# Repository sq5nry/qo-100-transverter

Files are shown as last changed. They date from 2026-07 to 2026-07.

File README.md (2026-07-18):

# qo-100-transverter





*[Wersja polska / Polish version](README_PL.md)*

## What it's about
- source-available, hardware and software project of a transverter for the [QO-100](https://amsat-uk.org/satellites/geo/eshail-2/) satellite. The outdoor version takes 1.5 days to assemble starting from bare PCB, bag of parts, and patience.
- complete up and down-converter below 199,99 € : [see the BOM](hw-trv/BOM.md)
- in-fab assembly automation in progress (*v0.3-snapshot*)

## Equipment and skills required
- knack for SMD soldering with stencil and solder paste
- patience for by-hand component placement
- 10x10 cm heat plate and ability to control the temperature profile
- multimeter
- set of fixed attenuators, a variable one and patch cables
- VNA+SA and a signal generator up to 3GHz minimum
- Pluto-like SDR to receive, measure, and generate signals during tests and adjustments
- RF power meter
- 30V 5A lab power supply with over-current protection
- ST-link programmer
- patience for drilling holes in aluminum enclosure
- patience for tapping 3 mm holes
- RF personal protective equipment rated to attenuate 2.4 GHz frequencies

## Features
- QO-100 narrow-band transponder SSB, CW, and Data operation with an HF-VHF transceiver
- ±0.25 ppm reference oscillator stability
- 6W of 2.4GHz output power
- 10m, 6m, 4m, 2m, 70cm bands supported, 5W input power maximum
- 738MHz filtered, receive output for signal supervision
- 25MHz reference oscillator for LNB: injected into the LNB feeder or the shared output
- PTT-over-coax supported
- splash-proof outdoor version

## Block diagram

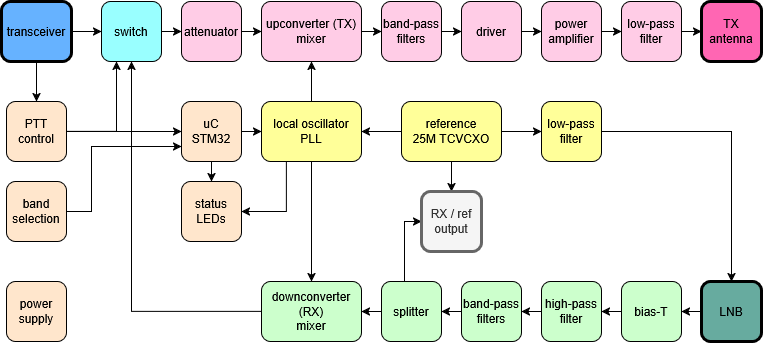
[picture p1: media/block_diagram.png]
block-diagram


## Operation

### Prerequisites

- 28V DC power supply offering 1.1A (31W), or
- 13.8V DC at 3.5A and using the Companion Box for voltage boost
- 60cm dish antenna suggested with 5W ERP according to AMSAT guidelines
- standard universal LNB (13/18V), 500mA fused
- standard PTT ground-to-transmit, or
- PTT-over-coax by transceiver or using the Companion Box to mix PTT and RF
- operation from 13.8V (1.1A) directly is possible with lower output power (2W max). Adequate linearity is not guaranteed.

### Basic procedures

1. Configure IF (Intermediate Frequency) corresponding to your transceiver setup using the three-position slide switch to select one of eight possible IF base frequencies.
2. IF can be updated on-the-fly, the change is indicated by a flashing green LED.
3. Connect DC power and PTT signal.
4. Switch on RX pre-amp in your transceiver.
5. Check the position of the received QO-100 mid beacon, adjust it to fall into the middle of the band using REF ADJ control with a small flat-head screwdriver.
6. Set your transceiver output power to 3–5W and adjust TX ATT control so that your signal is at the mid-beacon level. Lower power with a higher TX ATT setting is advised to minimize heat dissipation inside the transverter.

## Schematics

- [v0.3 schematics (current)](hw-trv/sch_v0.3-sh.pdf)
- [v0.2 schematics](https://github.com/sq5nry/qo-100-transverter/blob/77cc88346982ab3cb6913bec3531f18df363a01a/hw-trv/sch_v0.2.pdf) — release presented at [Ham Radio Friedrichshafen 2026](https://www.hamradio-friedrichshafen.com/trade-show-program/exhibitors/exhibitor?id=107515806) in [PZK](https://www.pzk.org.pl/) (Polish Amateur Radio Union) tent

> **⚠️ Note:** do not mount the OCXO subcircuit (error amplifier and heater components, connected via JP5). This circuitry is non-functional in the current release and will be removed in a future revision. The freed board space can instead be used for additional thermal insulation around the TCXO.

## Assembly

### Preparation

Gather all parts from the [BOM](hw-trv/BOM.md) and arrange them on your workbench before starting.
Verify IC orientation markings and keep ESD-sensitive parts (ICs, MOSFETs) in their packaging
until placement.

### Solder paste application

Apply solder paste through the PCB stencil. Two paste options have been tested:

- **Sn63Pb37** (183°C eutectic, e.g. Mechanic XG-50) — recommended; standard SnPb profile,
  widely available, easy to work with.
- **Sn42Bi58** (~138°C eutectic, e.g. ChipQuik SMD291 or Mechanic UV50) — low-melting-point
  alternative; useful if heat-sensitive components are a concern, but requires careful handling
  as bismuth alloys are more brittle and less compatible with lead-containing component finishes.

Clamp the stencil firmly over the PCB, apply paste with a squeegee in a single smooth stroke,
and lift the stencil straight up to avoid smearing. Inspect paste deposits under magnification
before placing components.

### Component placement

Place all SMD components onto the paste deposits. Work from smallest to largest — passives first,
then ICs. Pay close attention to pin-1 orientation on all ICs and polarised components.
QFN packages require careful centring over their pads; the paste surface tension will self-align
them slightly during reflow.

### Reflow

Place the populated PCB on the heat plate. Follow a standard **SnPb reflow profile**:

| Zone | Temperature | Duration |
|---|---|---|
| Preheat | 100–150°C | ~60 s |
| Soak | 150–180°C | 60–90 s |
| Reflow (above liquidus) | 183–215°C peak | 30–45 s |
| Cooldown | ramp down | natural |

Use hot air to assist reflow around QFN packages and larger thermal-mass parts (PA, DC-DC
converter). Watch for bridging on fine-pitch ICs.

### Inspection and rework

After reflow and cooldown, inspect all joints under magnification:

- Remove solder bridges with braid or a fine soldering iron tip.
- Add solder to any under-filled joints, particularly on exposed thermal pads of QFN/PQFN
  packages — use a soldering iron with flux through the heat-via holes on the bottom side.
- The bottom-side thermal vias do not need to be flush; they will be covered by thermal pads
  connecting to the heat spreader or enclosure floor.

### Through-hole parts

Solder the 5W power resistor by hand after SMD reflow. Mount the TCVCXO with polyester
tape and foam fitting as described in the enclosure assembly notes.

### EMI shields

The PCB has footprints for SMD metal EMI shields over sensitive sections. Mounting the shield over the IF Unit is important for stability. Shielding the switched-mode power supply section and TCXO is recommended but not critical.

### EMI absorber

Most of enclosure types require absorption foams in PA area to help suppress self-oscillations and minimize parasitic coupling between stages. The amplifier may start self-oscillations at a frequency between 2.2-2.5GHz with full power without the absorber. \
See gallery section for a poor's-man approach.

### PCB cleaning

Wash the assembled PCB thoroughly with isopropanol to remove all flux residues before
proceeding. Flux contamination on the board surface can significantly affect 2.4GHz circuit
behaviour — altering tuning, increasing losses, and making RF adjustments unreliable.
Allow the board to dry completely before applying power.

### Power-up and initial checks

Connect power and PTT cables. Supply 28V with the current limit set to 50mA. Measure the
following test points and verify voltages before proceeding:

1. Check 13V and 5V test points first.
2. If those are correct, verify: 3V (analog), 3V (digital), 3.3V (reference oscillator),
   3V (MCU), 9V, and 1.8V.

If any rail is missing or out of range, do not proceed — investigate before applying full power.

### Firmware

Flash the firmware using **STM32CubeProgrammer** via the ST-LINK interface and the SWD ISP
header. A firmware release binary is provided; to build from source use **STM32CubeIDE**.

After programming, the **PLL LOCK** indicator should illuminate. If it does not, check the
25MHz reference oscillator signal.

### PA bias adjustment

Set the quiescent drain current (Idq) for the 2.4GHz PA stages:

- 1st stage: **15mA**
- 2nd stage: **75mA**

Before adjusting, raise the lab supply's overload protection (current limit) to about
**250mA** so it does not trip during bias trimming.

To measure Idq, cut the respective drain supply PCB trace and insert an ammeter in series or just calculate current delta on the lab supply.
Adjust the bias trimmer for each stage until the target Idq is reached, then bridge the cut
with solder.
Adjust the position of C87 in the PA output circuit for highest stage gain.

### PA gain and output matching

Measure the PA gain and adjust the position of C88 to obtain **28–30dB** gain — slide C88 along the output line toward the thicker section. If that alone does not maximise gain, add 0.8pF in parallel with C88. Do not mount
the low-pass filter (LPF) elements yet — bridge the LPF inductor footprint with a strip of
copper foil instead, so the PA output can be measured without the potentially mismatched filter.

Once the gain is set, mount the LPF inductor and adjust it for a maximum insertion loss of
**1dB at 2.4GHz**.

Set the overload (overcurrent) protection threshold to **1.1A**.

Connect an RF power meter to the 2.4GHz TX output socket and adjust the TX path for **6W**
output across your expected input power range (1–5W).

> **⚠️ Warning:** do not increase input power in an attempt to reach 6W until PA gain is at least 28dB. PA chip will overheat and operate non-linearly. I bricked one PA after overloading its input with just 17dBm.

> **⚠️ Warning:** do not drive the PA past **9..12W** output — exceeding this limit pushes the
> stage into non-linear operation, causing spectral splatter and interference to other users.

> **⚠️ Note:** the PA chip tolerates antenna mismatch well — SWR up to 10:1 on the 2.4GHz
> TX port will not damage it. However, operating with no load connected may cause
> self-oscillation in the 2.2–2.5GHz range; the on-board 1.5A resettable fuse will limit
> the resulting current in that event.

## Circuit description

### Transmit path

The transceiver signal (up to 5W / +37dBm) passes through a variable 35–42dB attenuator,
reducing it to approximately −8dBm at the mixer input. A diode protection limiter with a
clipping level starting softly at +4dBm guards the mixer — this is to limit damage in case you connect 100W for a longer time. Note that sustained high-power overshoots may still damage the PA by exceeding its maximum input level even if the mixer itself survives. \
The signal enters a balanced Gilbert-cell mixer (RFFC2071). The mixer's wideband 4:1 output transformer provides differential symmetry that helps cancel LO leakage, minimising it before the signal
even reaches the downstream filter. Although slightly more expensive than a narrowband balun
chip, the wideband transformer's superior symmetry keeps LO leakage below −32dBc relative
to the upper sideband with only two SAW filters — most critically on the 29MHz band, where
LO leakage lands closest to occupied spectrum. The TX mixer on 10m is intentionally operated at a reduced bias current, which directly reduces LO leakage at its output. \
The output is filtered by a 2.4GHz bandpass filter to further suppress any residual LO leakage and the image frequency. The two TX bandpass filters are inter-stage matched using a parallel 0.8pF capacitor; this matching network optimises power transfer between the filter sections. A driver stage amplifies the signal to +12dBm, followed by a 29dB LDMOS power amplifier — whose input is matched to 50Ω using a short high-impedance transmission line — and a low-pass filter, delivering +38dBm (6W) to
the TX output socket. \
1dB and 3dB fixed attenuation pads improve impedance matching, distribute gain, and improve amplifier stability. Their 50Ω terminations also
provide convenient probe attachment points when measuring gain between individual stages. \
Image attenuation is 40dB on 10m.
Total conversion gain is 2–9dB; about 0.8–4W from the transceiver will produce 6W output.

### Receive path

Both the LNB supply voltage and the 25MHz reference signal (along with its harmonics up to 125MHz) are injected via a bias-T, which must provide sufficient RF isolation across the full 25–738MHz range where these signals share the same junction. The reference signal is low-pass filtered to 125MHz before injection. \
The received 738MHz IF from the LNB passes through a high-pass filter (so as not to hammer the input SAW filters with the reference oscillator) and two cascaded SAW filters centred around 738MHz. Then follows optional splitter to tap IF to the external RX AUX socket. Release v0.2 uses resistive splitter but it's advised to use minimum-loss option as in v0.3-sh. If you don't need the RX AUX output, do not mount the splitter parts.\
From the mixer output the signal passes through a PIN diode switch to the shared TRX socket. The switch's bias-T is built from three inductors in series, chosen to present at least 1kΩ of reactance at
every supported IF band. \
The input attenuator is always present on the RX path — enable the RX preamplifier in your
transceiver to compensate. The receive path does not add amplification (to keep the cost low) and relies on typical LNB signal levels so as not to degrade the SNR with noise from the RX chain. \
On 70cm IF the strongest signals come at S9 level with RX preamp on, mid-beacon is S7.

### Control

The STM32L0 microcontroller configures the RFFC2071 PLL for the RX and TX frequencies corresponding to the IF band selected by the DIP switch. In addition, mixer bias currents ate also configurd per band. On PTT transitions, the logic switches between the TX and RX PLL register banks in the RFFC2071. The PTT signal is a logical OR from the physical PTT line and the coax (PTT-over-coax).

### Indicators

The blue LED indicates that the PLL synthesizer is locked — the MCU has configured the PLL, the 25MHz reference is running, and the LO frequency is being generated. Mixer bias currents are configured according to IF band.

The green LED blinks in RX mode and is lit continuously in TX mode. On startup and on IF band change, it blinks once per IF position number (1–8).

## Jumper configuration

### Jumper reference

| Jumper | Name | Default | Function |
|---|---|---|---|
| JP1 | AUX SEL | Reference | Selects what the RX/REF (AUX) socket outputs: **Reference** (25MHz) or **RX** (738MHz) |
| JP2 | RX SPLIT | no-split | Part of RX split — change together with JP4. Change position only if you want RX in AUX socket. |
| JP4 | RX SPLIT | no-split | Part of RX split — change together with JP2. Change position only if you want RX in AUX socket. |
| JP5 | OVEN | disconnected | Reserved for OCXO option; disabled in v0.2 |
| JP6 | REF ROUTE | AUX path | Routes the 25MHz reference toward the AUX socket (default) or toward the LNB feeder (also check JP7) |
| JP7 | REF TO LNB | open | Solder to mix the 25MHz reference signal into the LNB feeder coax. This jumper enhances signal integrity when the REF signal isn't routed to the LNB feeder. "Open" when you don't want to mix the REF with the LNB feeder, "Connected" to inject the REF into the LNB feeder. |

### Typical usage scenarios

**1. RX/REF (AUX) socket outputs 25MHz reference** *(default — no changes needed)*

Use this to supply 25MHz reference to an external device via the AUX socket.

| JP1 | JP2 | JP4 | JP6 | JP7 |
|-----|-----|-----|-----|-----|
| default (Reference) | default | default | default (AUX path) | open |

---

**2. 25MHz reference injected into LNB feeder cable**

Use this when the LNB is fed its reference via the coax (no separate reference cable needed).

| JP1 | JP2 | JP4 | JP6 | JP7 |
|-----|-----|-----|-----|-----|
| default | default | default | **change (LNB path)** | **solder** |

---

**3. RX signal (738MHz) on AUX socket**

Use this to route the received downconverted signal to an external SDR or receiver via the AUX socket.

| JP1 | JP2 | JP4 | JP6 | JP7 |
|-----|-----|-----|-----|-----|
| **change (RX)** | **change** | **change** | default | open |

---

**4. Reference injected into LNB feeder + RX signal on AUX socket**

Combines use cases 2 and 3: LNB gets its reference via coax, AUX socket carries the RX signal.

| JP1 | JP2 | JP4 | JP6 | JP7 |
|-----|-----|-----|-----|-----|
| **change (RX)** | **change** | **change** | **change (LNB path)** | **solder** |

---

## Gallery

Video thumbnail (https://drive.google.com/file/d/1cbVlMBV8zS9o48hG52KBiPKmD1HPmWjP/view?usp=drive_link)

*Click the image to watch the video.*

Output power video thumbnail (https://drive.google.com/file/d/1jGGn86MhkM-9hL6HgY638JuyBKbzmVd1/view?usp=drive_link)

*Output power — click to watch. 40dB/50W att. + 20dB SMA att (39.5+19,5=59dB at 2.4GHz)*

Infrared video thumbnail (https://drive.google.com/file/d/16R6eq9bAkn6X3CiZJTOIlDRJh-qXqAGV/view?usp=drive_link)

*Infrared video of the PCB during PA test — passive cooling via aluminum enclosure. Click to watch.*

Power measurements video thumbnail (https://drive.google.com/file/d/1BobpsWnM3RhQmgtJEgMQ4XA69L-facsb/view?usp=drive_link)

*Power measurements — click to watch. Heat-pipe directly at PA.*

### Finished units

<table>
<tr>
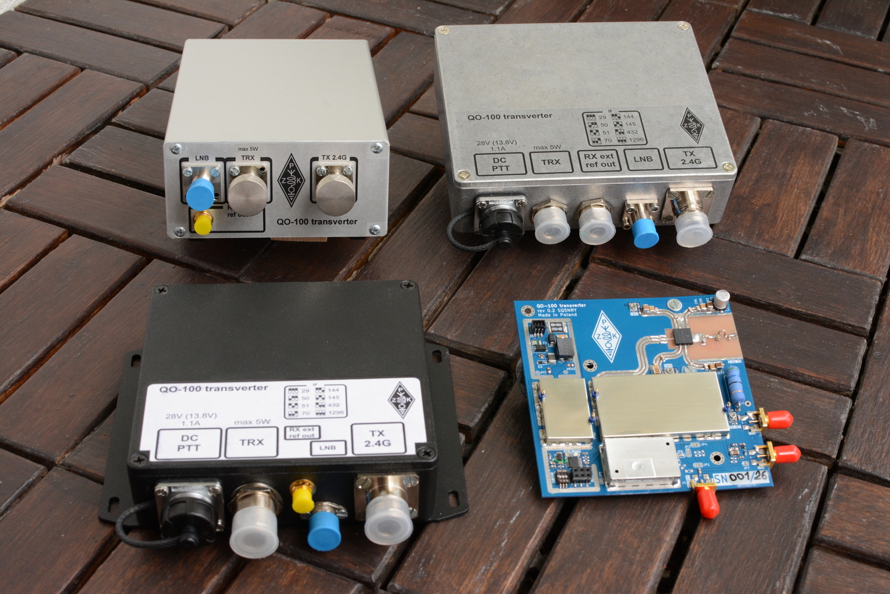
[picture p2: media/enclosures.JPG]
various realizations
<td><br><em>cabinet, outdoor classic, outdoor mini, bare bone</em></td>
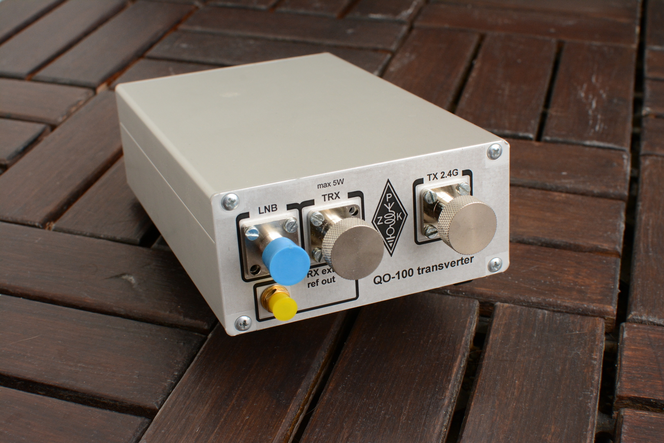
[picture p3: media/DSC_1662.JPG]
shack version
<td><br><em>cabinet version</em></td>
</tr>
<tr>
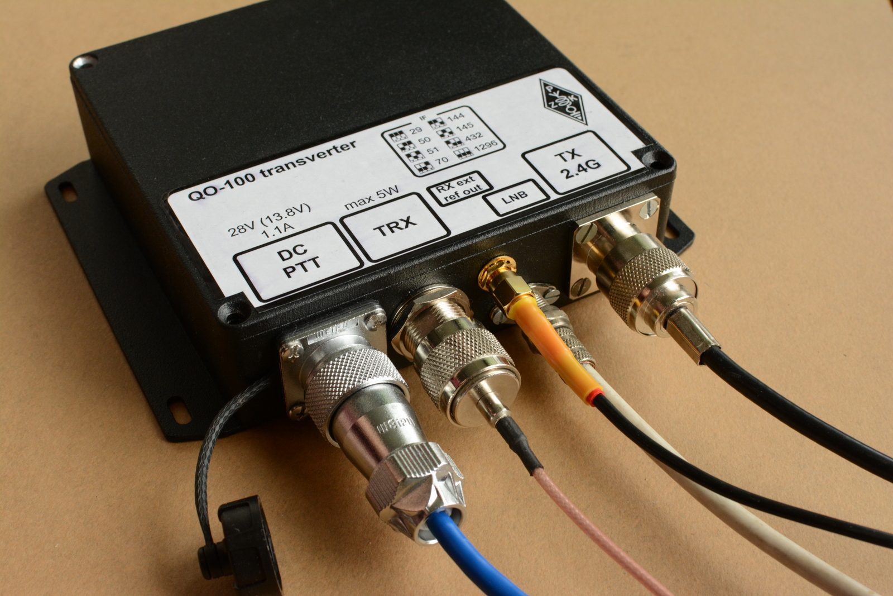
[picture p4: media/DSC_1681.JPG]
outdoor small
<td><br><em>outdoor mini</em></td>
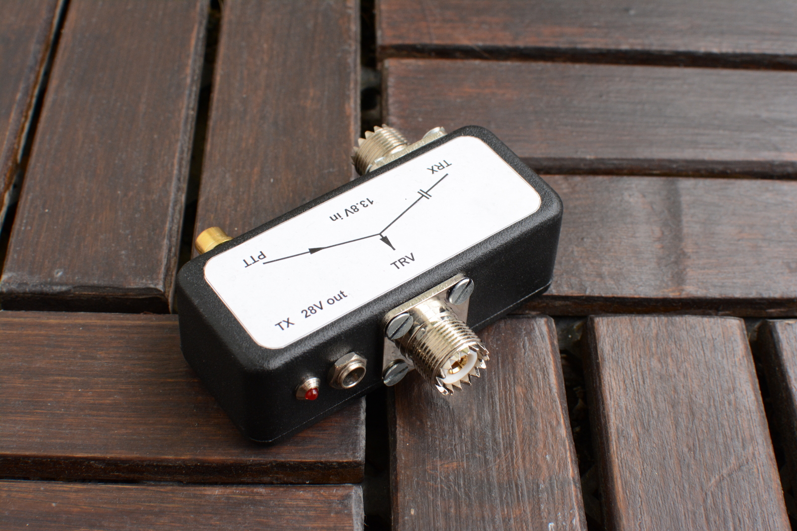
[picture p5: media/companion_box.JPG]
companion box
<td><br><em>Companion Box</em></td>
</tr>
<tr>
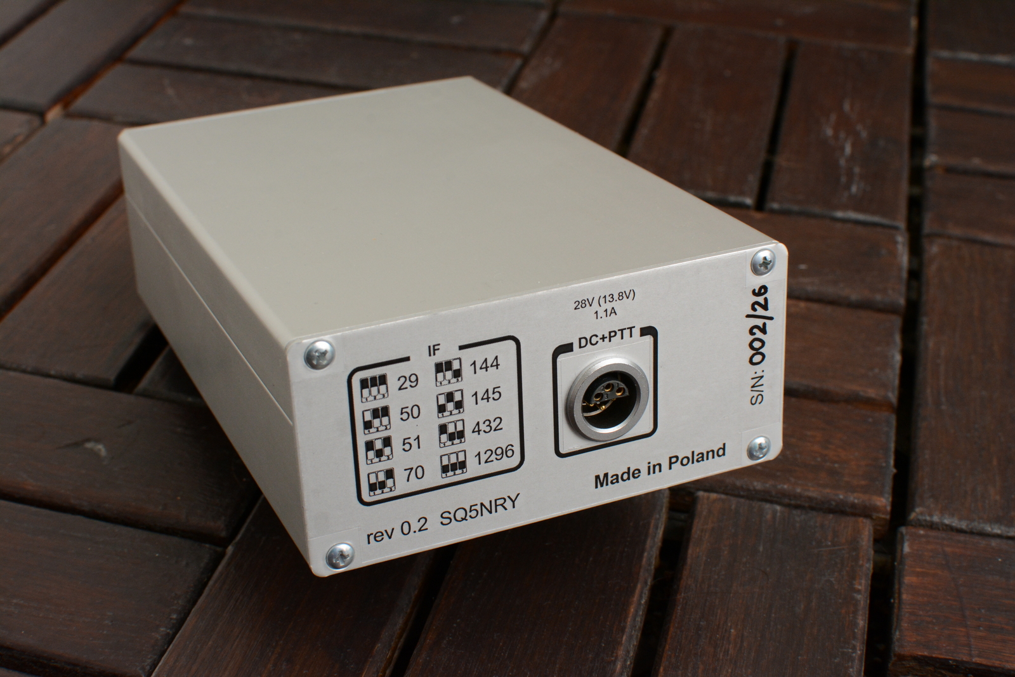
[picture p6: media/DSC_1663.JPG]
cabinet version, back plate
<td><br><em>cabinet version, back plate</em></td>
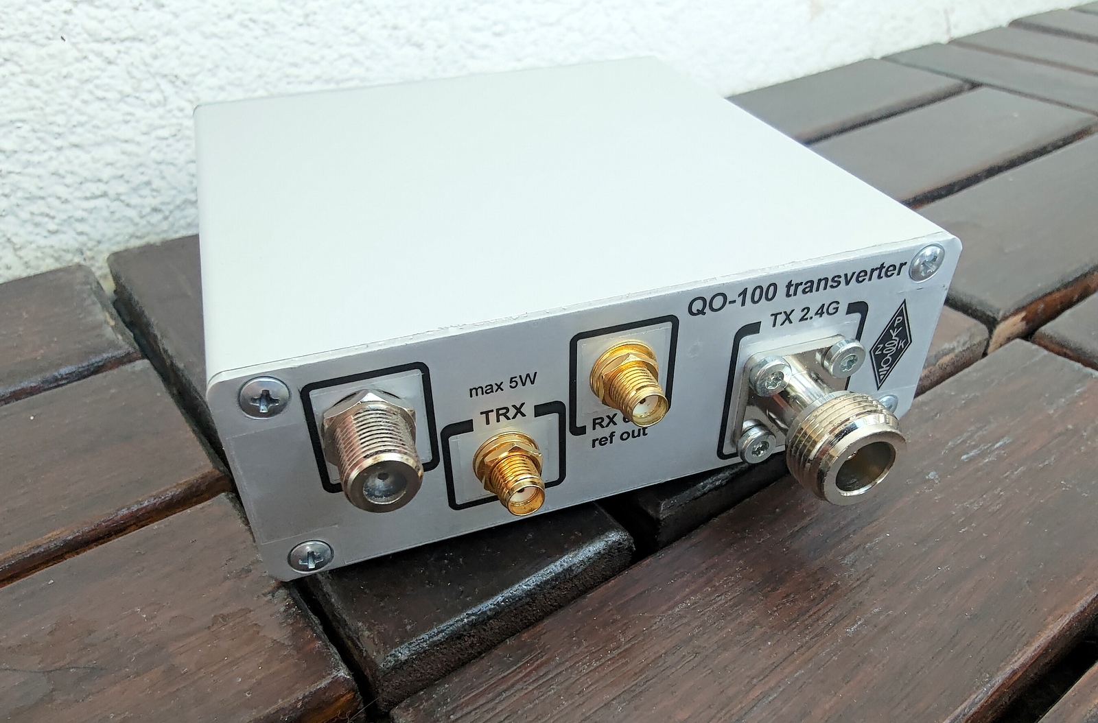
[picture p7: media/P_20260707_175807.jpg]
cabinet tiny
<td><br><em>cabinet mini</em></td>
</tr>
</table>

### Enclosure internals

<table>
<tr>
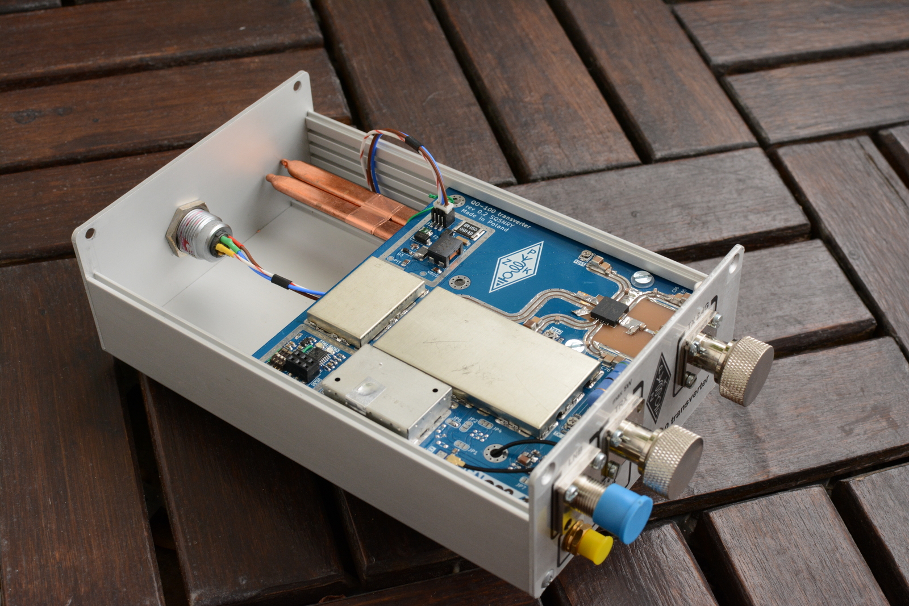
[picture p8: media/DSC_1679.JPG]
cabinet version inside
<td><br><em>cabinet version</em></td>
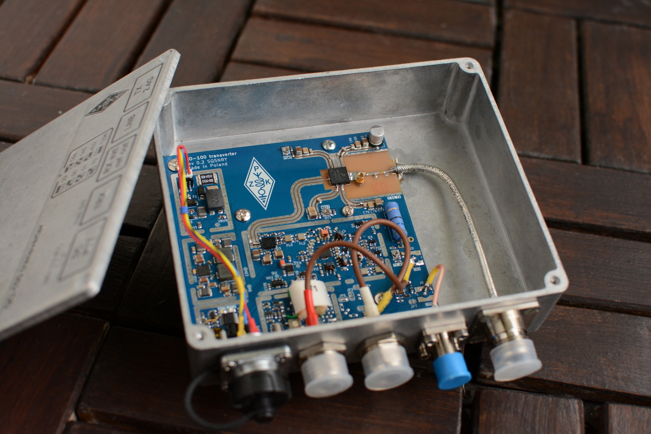
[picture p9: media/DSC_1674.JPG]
outdoor classic inside
<td><br><em>outdoor classic</em></td>
</tr>
<tr>
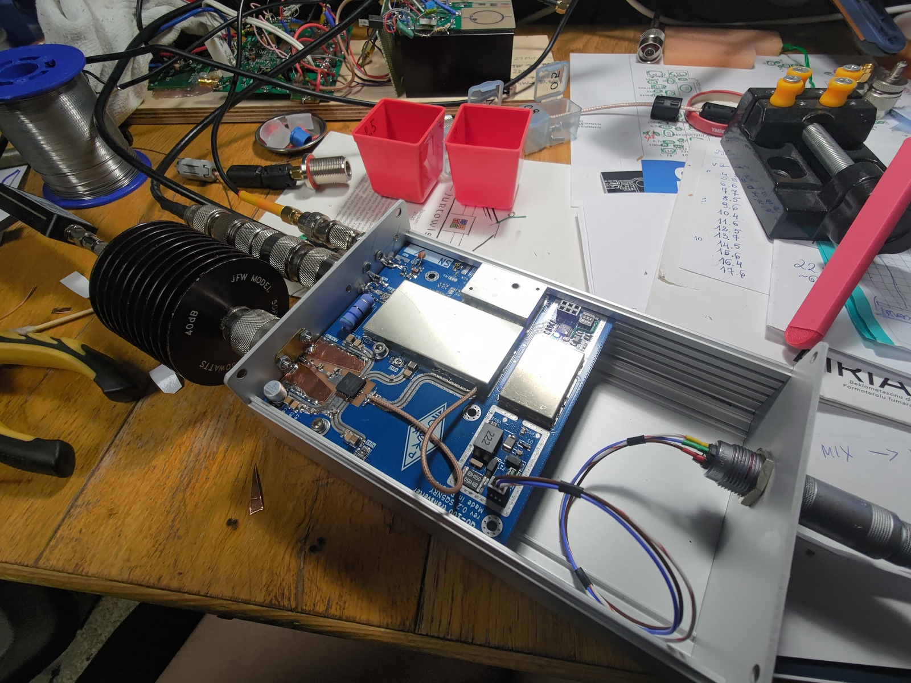
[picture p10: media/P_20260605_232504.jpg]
cabinet version during integration
<td><br><em>cabinet version</em></td>
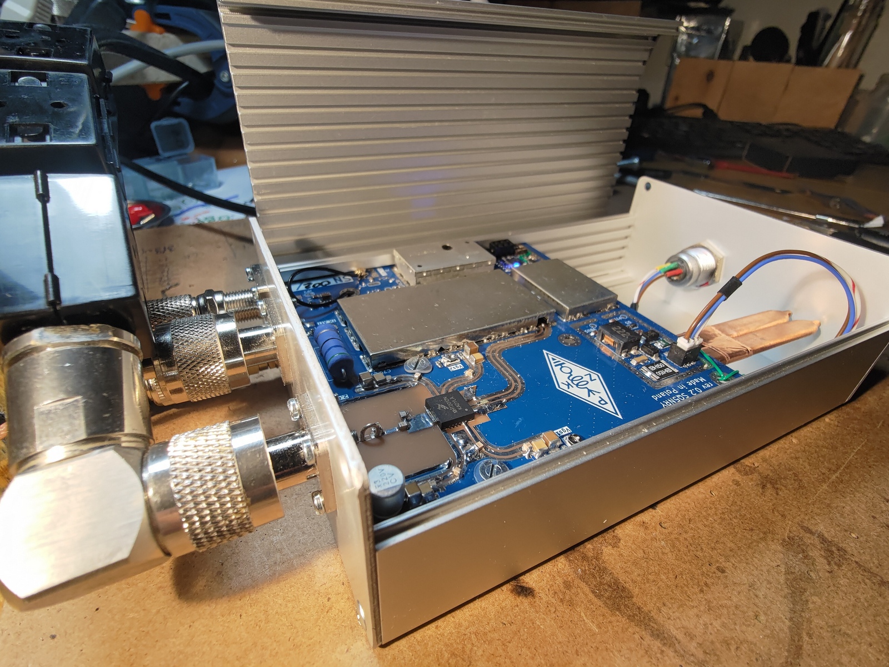
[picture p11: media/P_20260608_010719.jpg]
cabinet version open
<td><br><em>cabinet version</em></td>
</tr>
<tr>
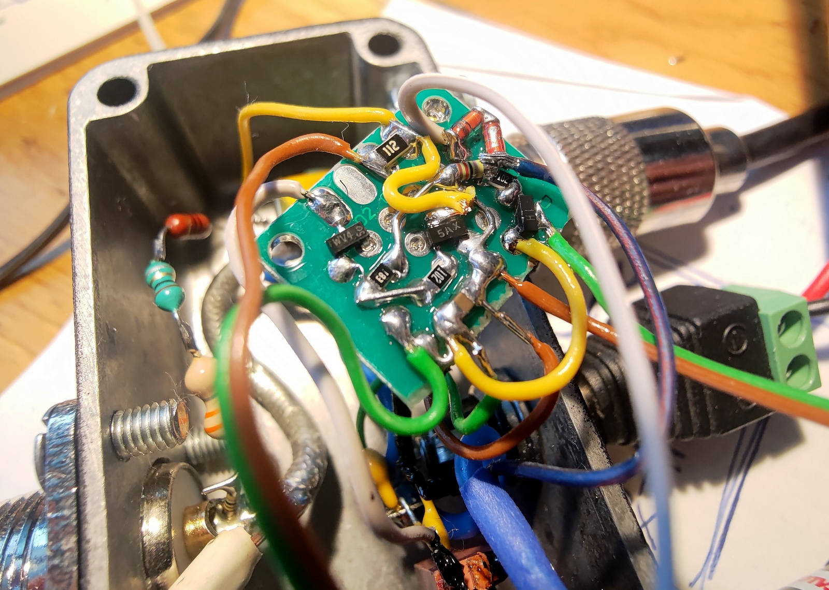
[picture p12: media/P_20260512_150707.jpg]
Companion Box proof-of-concept
<td><br><em>Companion Box proof-of-concept</em></td>
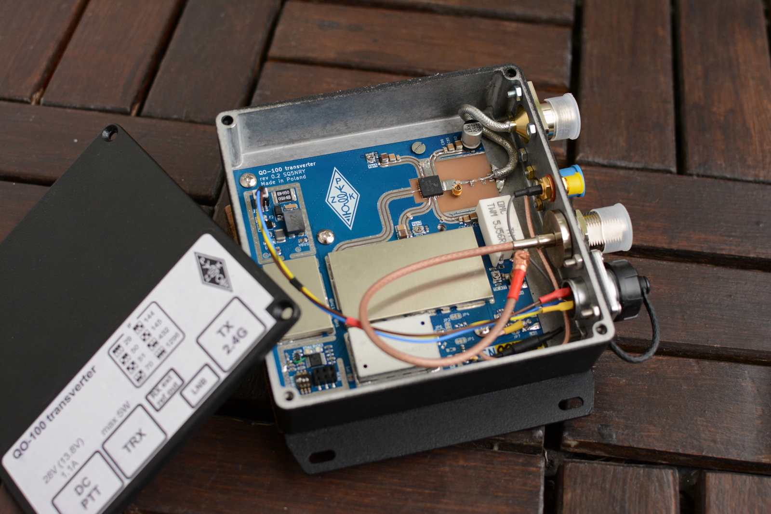
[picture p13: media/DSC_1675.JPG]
outdoor mini open
<td><br><em>outdoor mini</em></td>
</tr>
</table>

### PCB assembly

<table>
<tr>
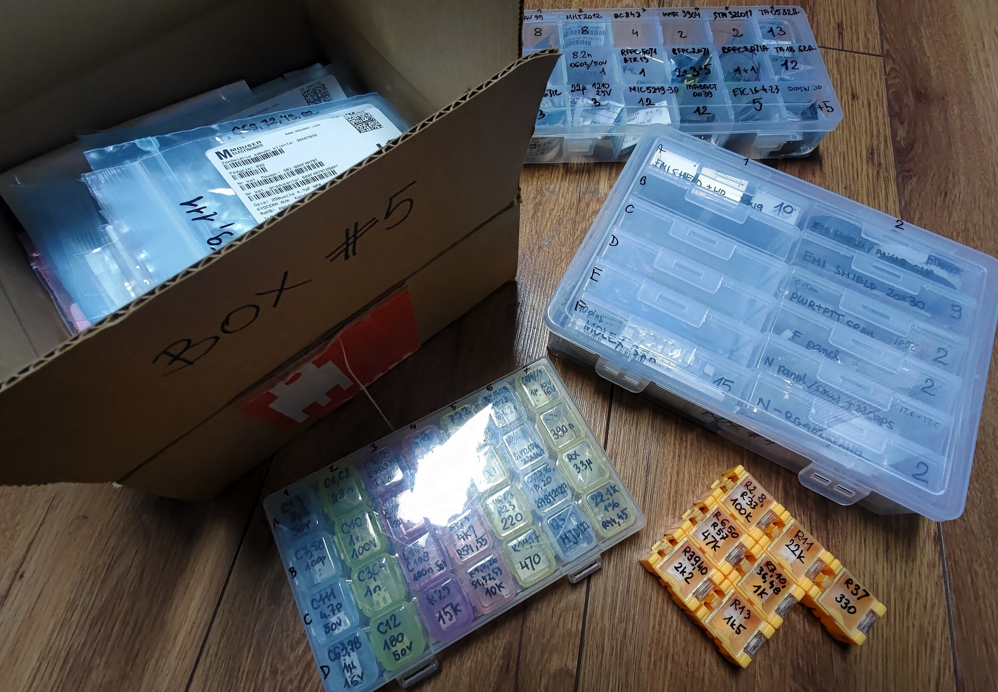
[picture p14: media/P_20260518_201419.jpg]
component delivery
<td></td>
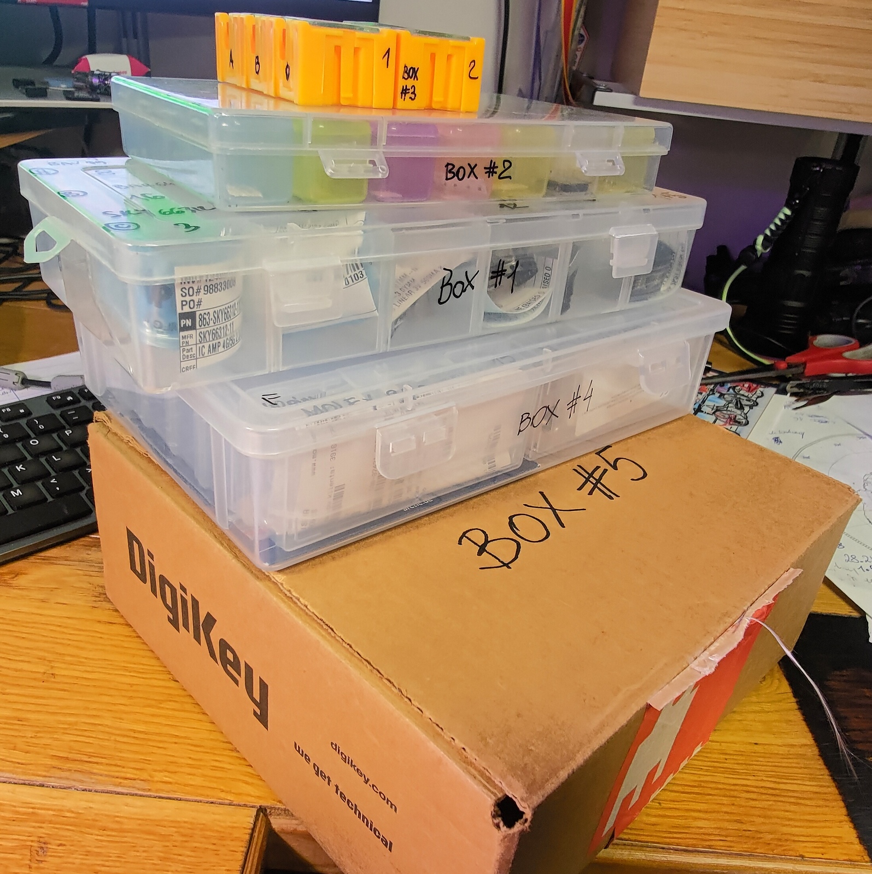
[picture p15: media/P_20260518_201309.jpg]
component kits unpacked
<td></td>
</tr>
<tr>
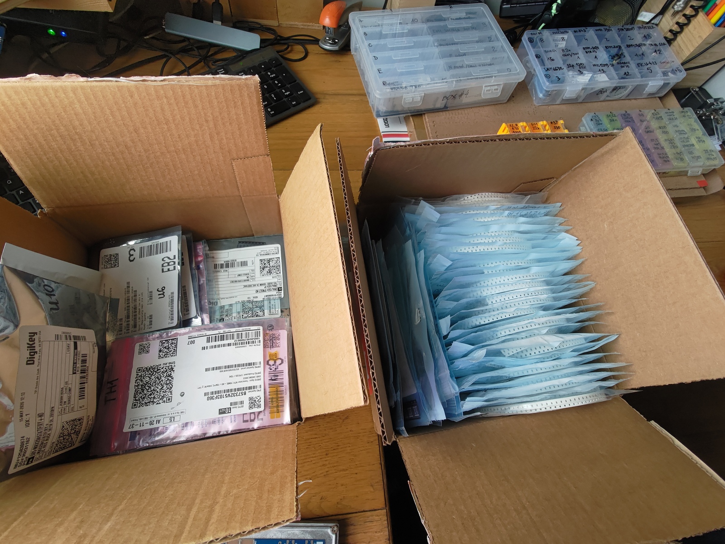
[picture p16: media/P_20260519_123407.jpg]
SMD component reels and bags
<td></td>
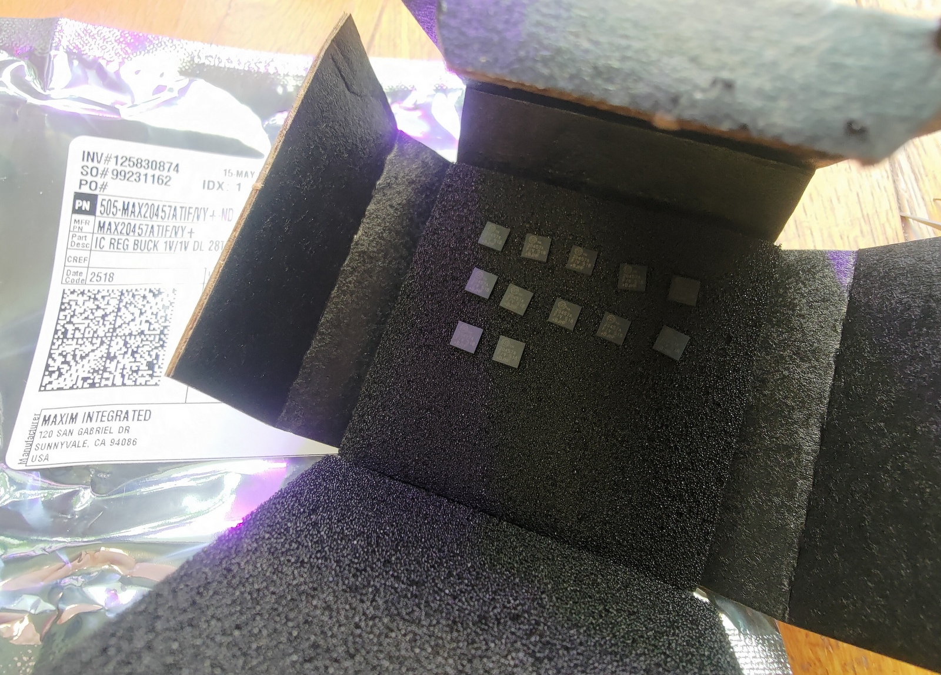
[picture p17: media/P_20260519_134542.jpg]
MAX20457 ICs in ESD packaging
<td></td>
</tr>
<tr>
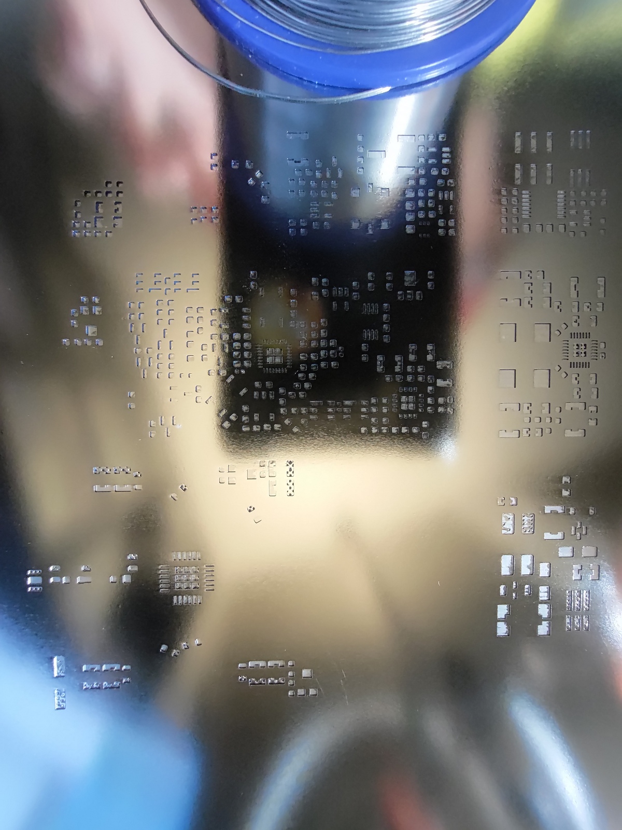
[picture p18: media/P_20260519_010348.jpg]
solder stencil
<td></td>
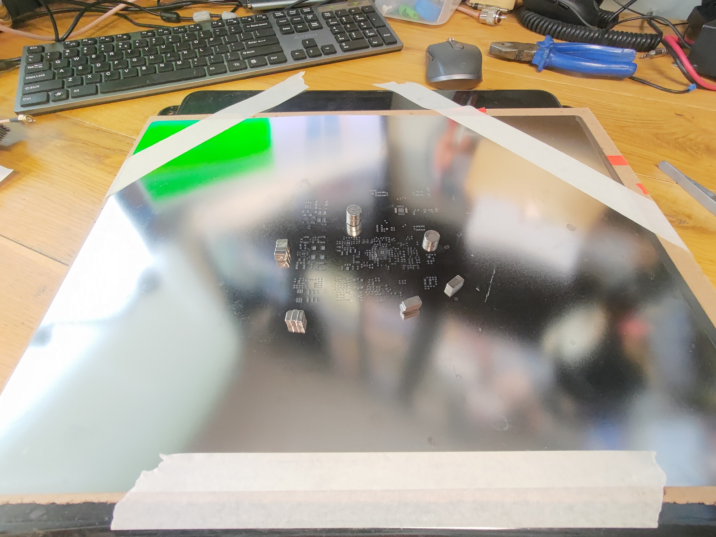
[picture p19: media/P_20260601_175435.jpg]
stencil clamped over PCB
<td></td>
</tr>
<tr>
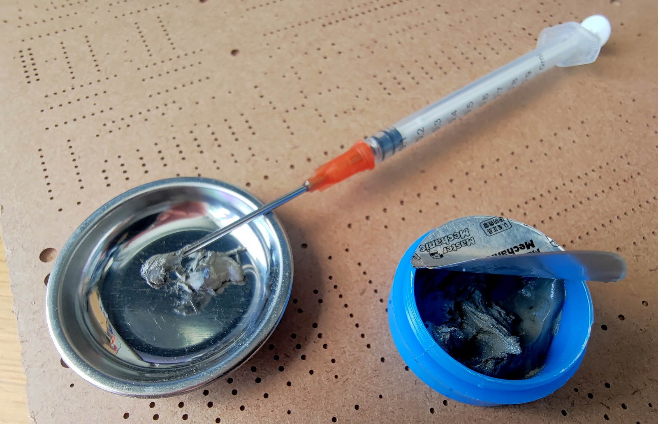
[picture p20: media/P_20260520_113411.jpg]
solder paste preparation
<td></td>
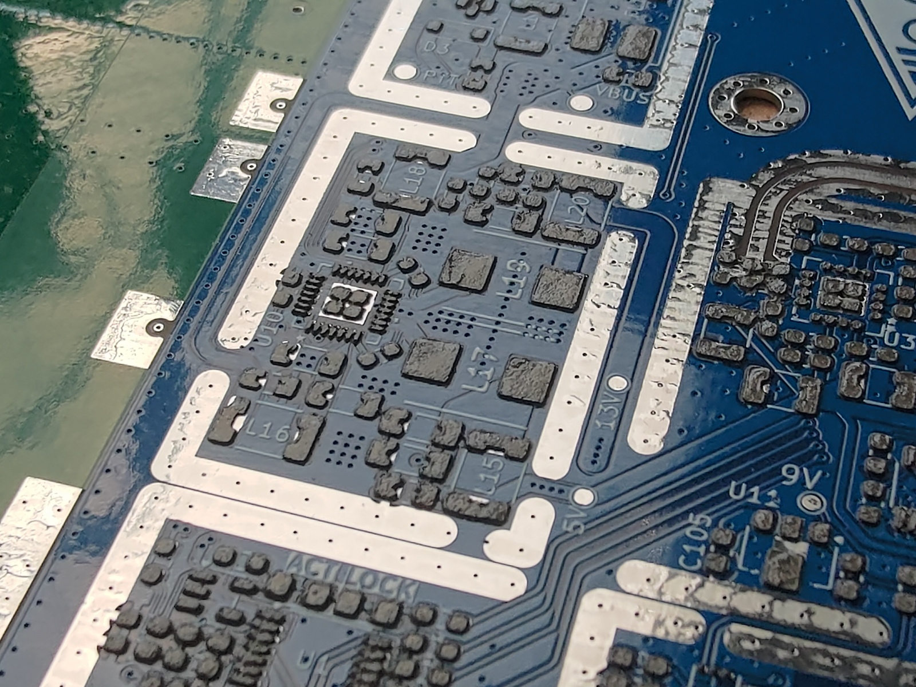
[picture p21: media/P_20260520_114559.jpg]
solder paste applied
<td></td>
</tr>
<tr>
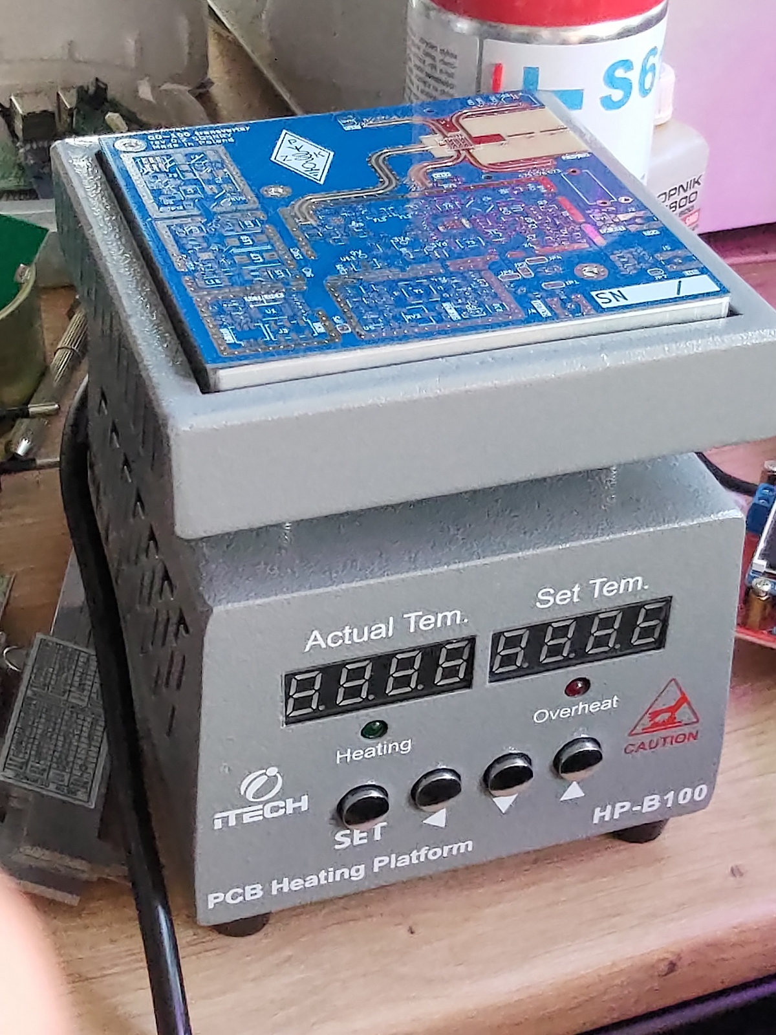
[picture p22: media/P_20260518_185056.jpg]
reflow on heating platform
<td></td>
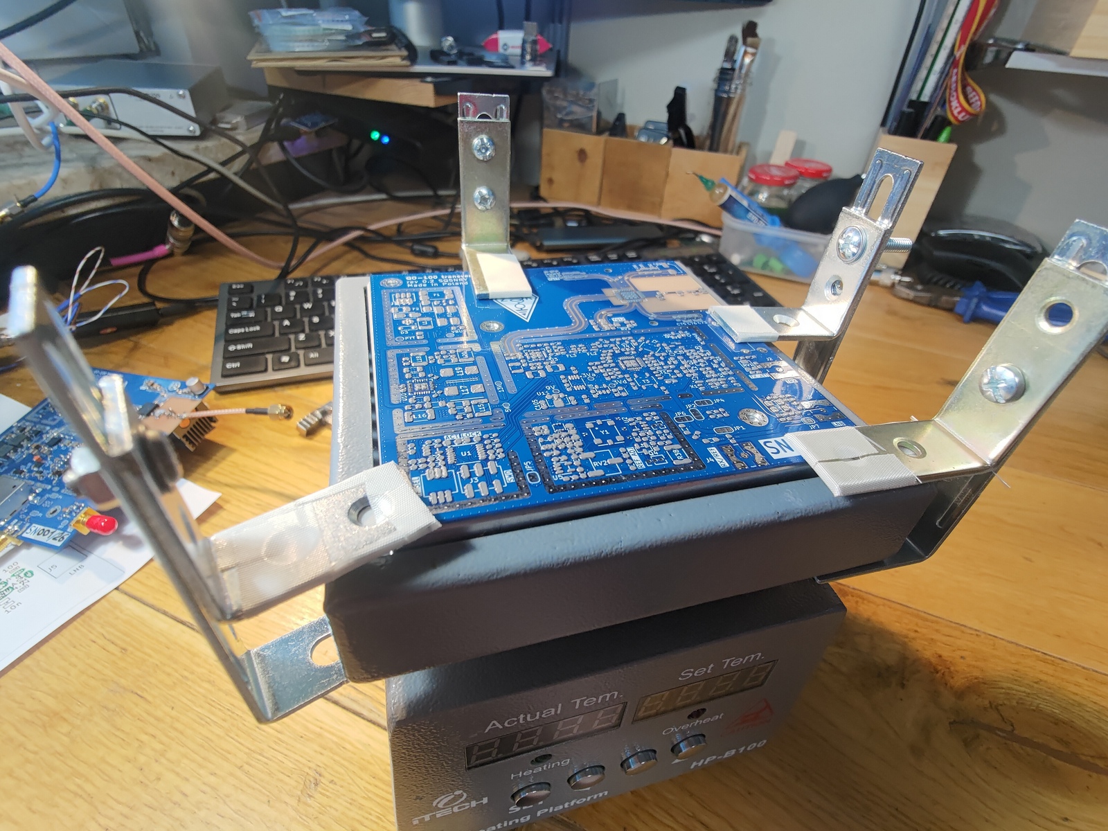
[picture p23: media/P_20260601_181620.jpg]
reflow in progress
<td></td>
</tr>
<tr>
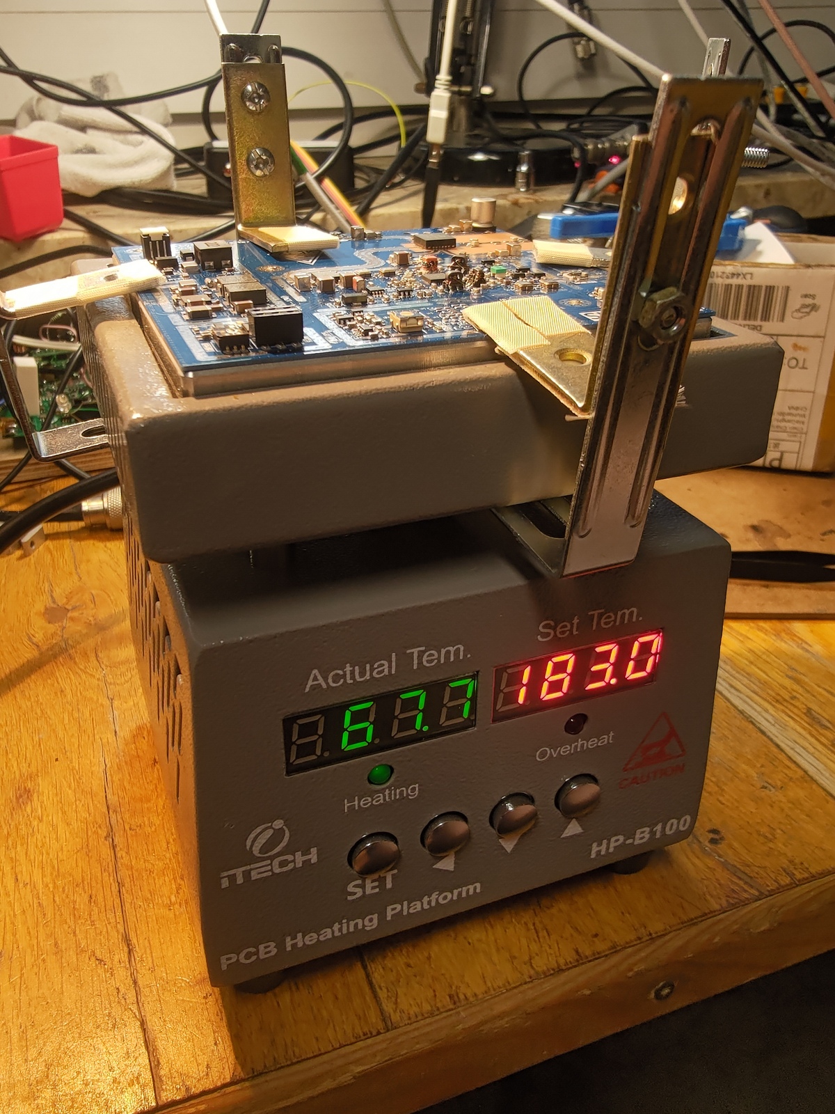
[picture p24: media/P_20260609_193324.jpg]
hot plate component rework
<td></td>
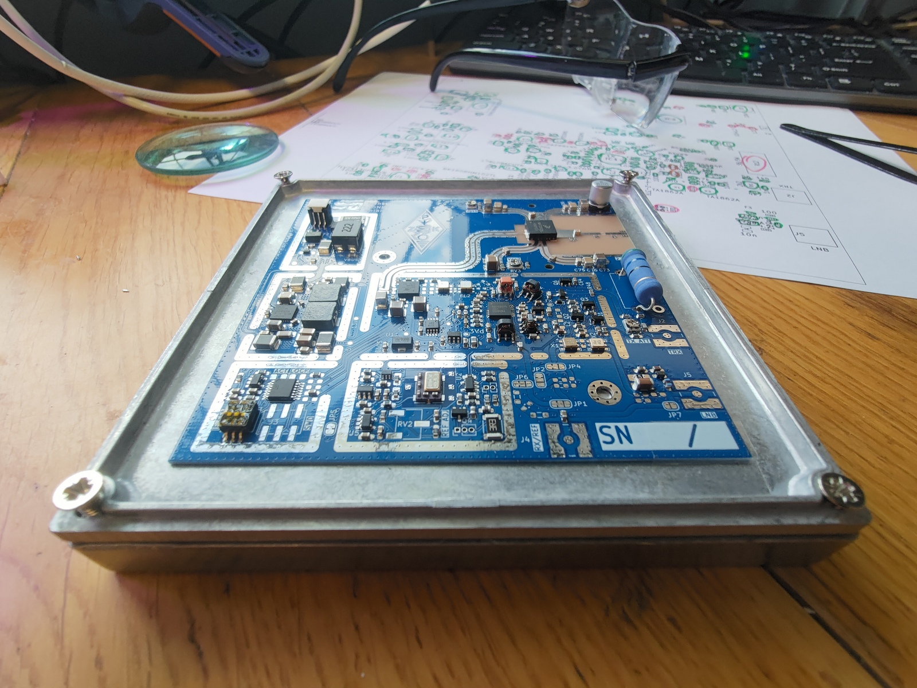
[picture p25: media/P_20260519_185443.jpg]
first assembled v0.2 board in frame
<td></td>
</tr>
<tr>
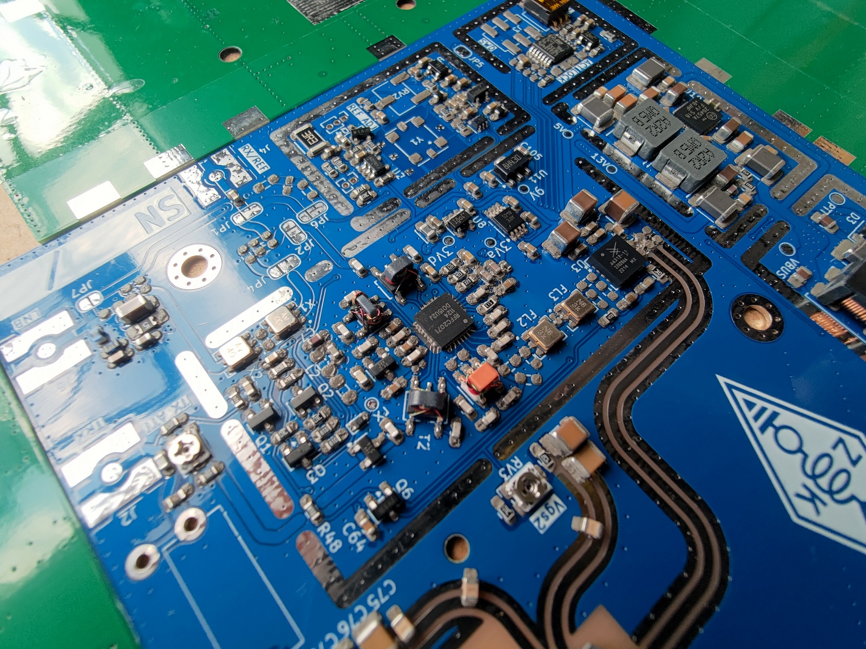
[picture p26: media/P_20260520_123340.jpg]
populated PCB panel
<td></td>
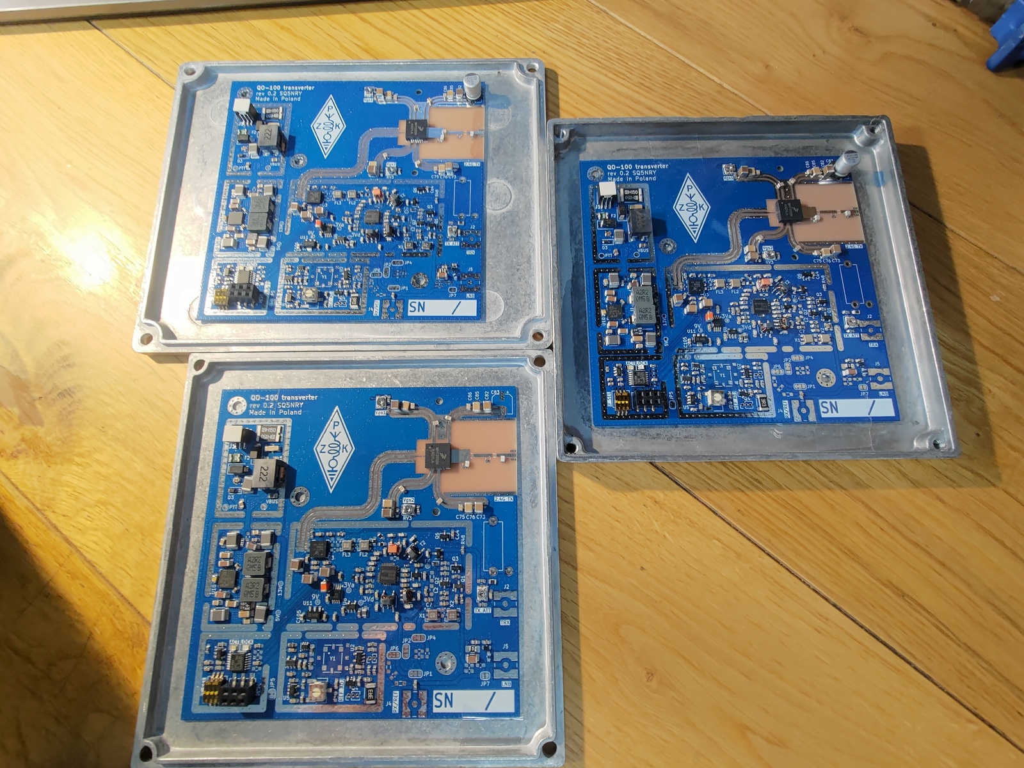
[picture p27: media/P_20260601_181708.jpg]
assembled batch
<td></td>
</tr>
</table>

### PCB details

<table>
<tr>
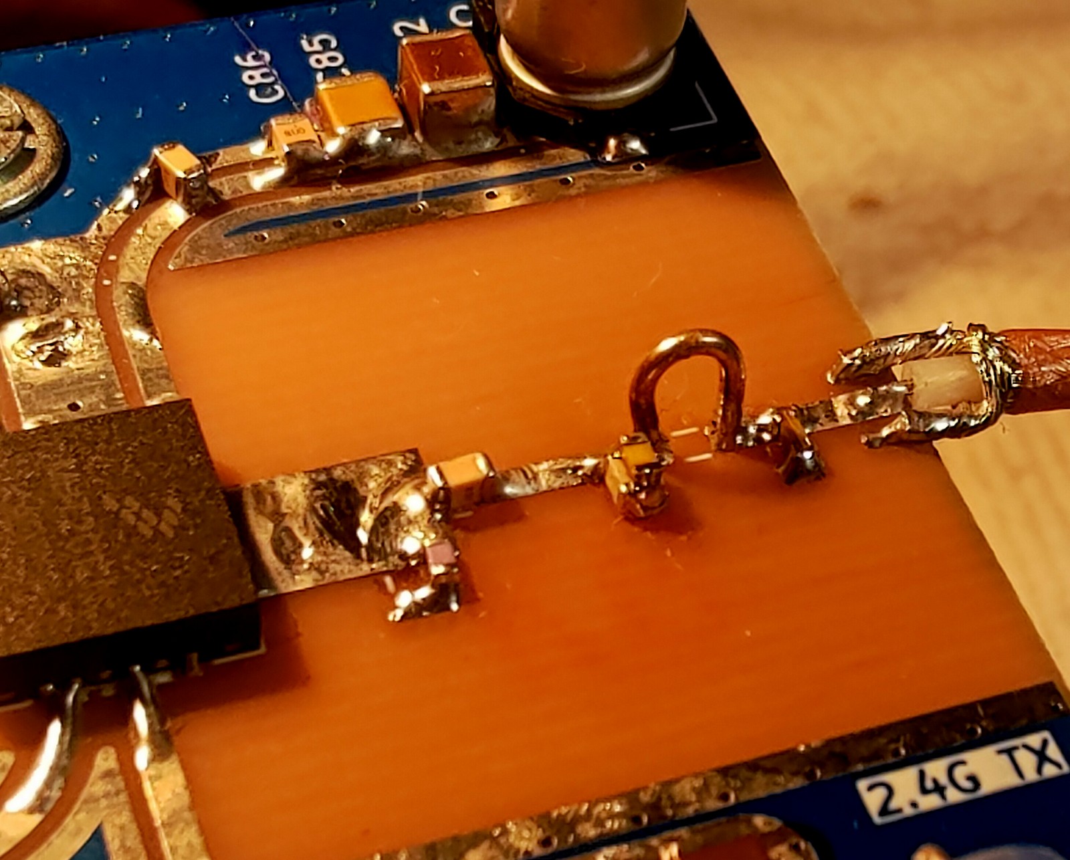
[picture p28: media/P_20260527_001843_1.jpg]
2.8GHz low-pass filter
<td><br><em>2.8GHz low-pass filter</em></td>
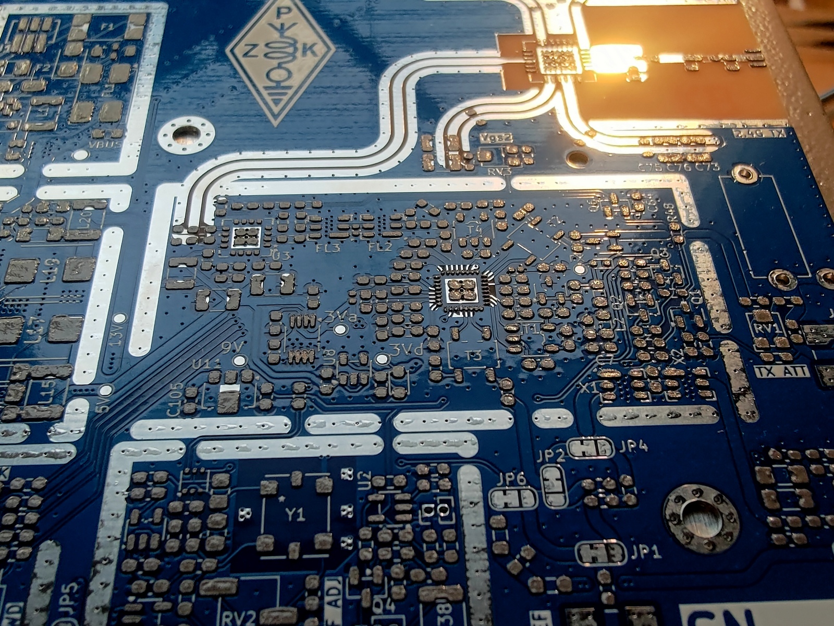
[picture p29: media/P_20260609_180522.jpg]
PCB bottom side
<td></td>
</tr>
<tr>
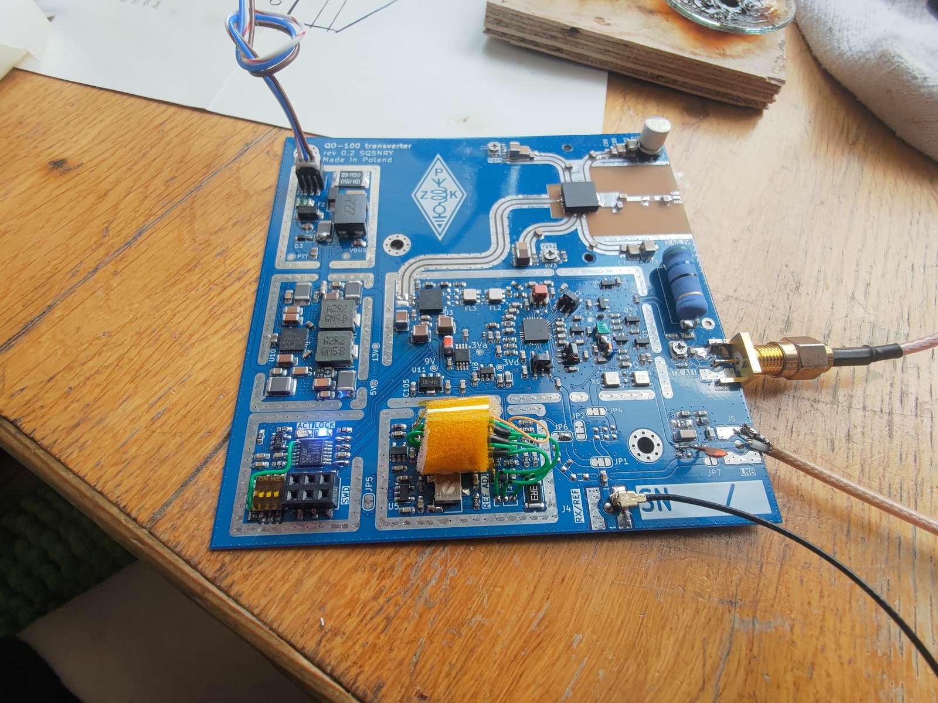
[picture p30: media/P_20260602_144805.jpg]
v0.2 board populated
<td></td>
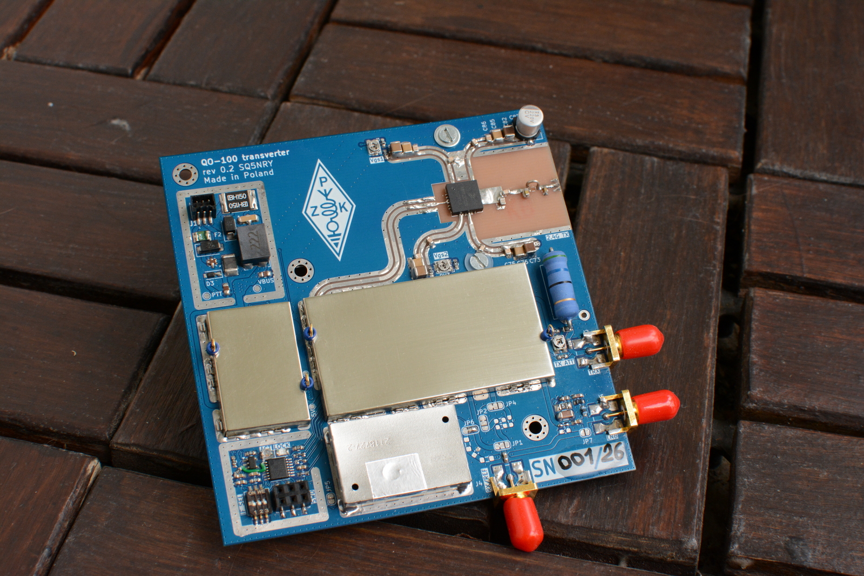
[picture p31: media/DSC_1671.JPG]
bare populated v0.2 PCB
<td></td>
</tr>
<tr>
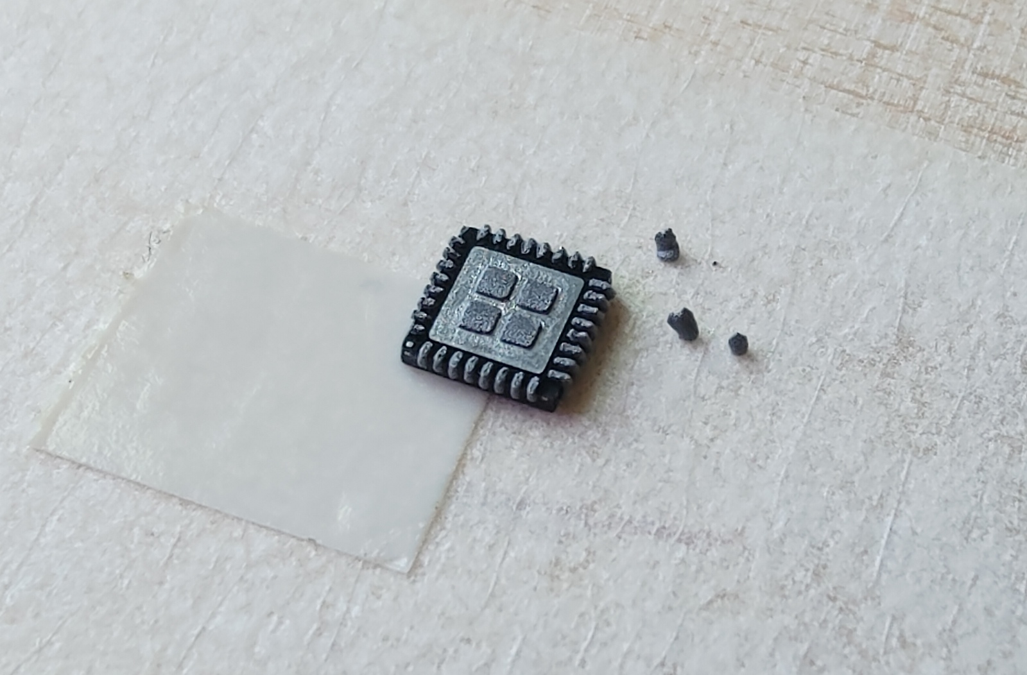
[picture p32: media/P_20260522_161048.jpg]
replacing IF chip
<td><br><em>replacing IF chip</em></td>
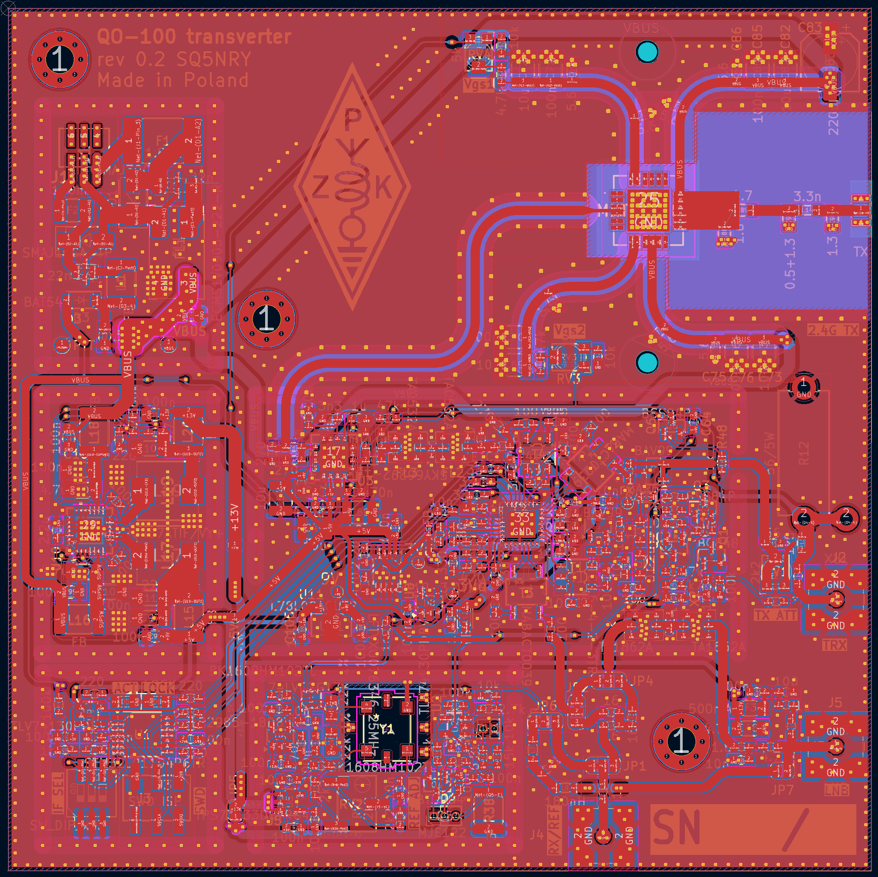
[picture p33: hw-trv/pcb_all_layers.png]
PCB all layers
<td></td>
</tr>
</table>

### EMI absorbers

<table>
<tr>
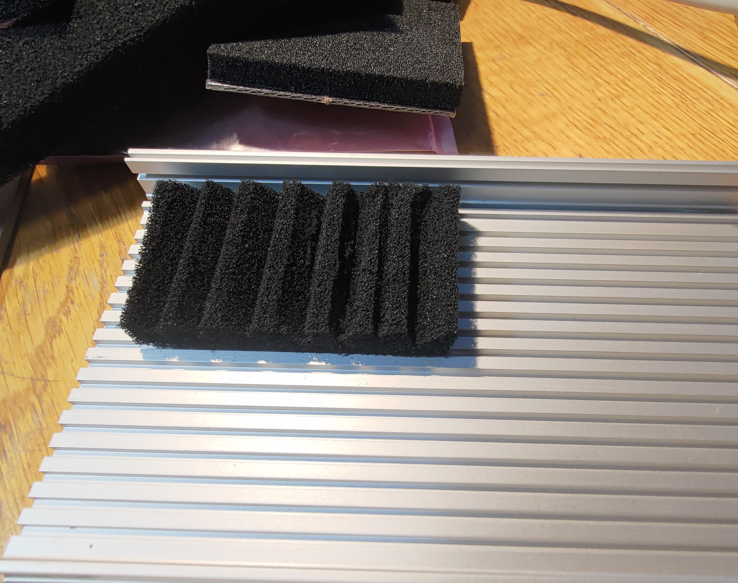
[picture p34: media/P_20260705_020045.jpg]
EMC absorber fitting
<td></td>
<td>EMC absorber detail</td>
</tr>
<tr>
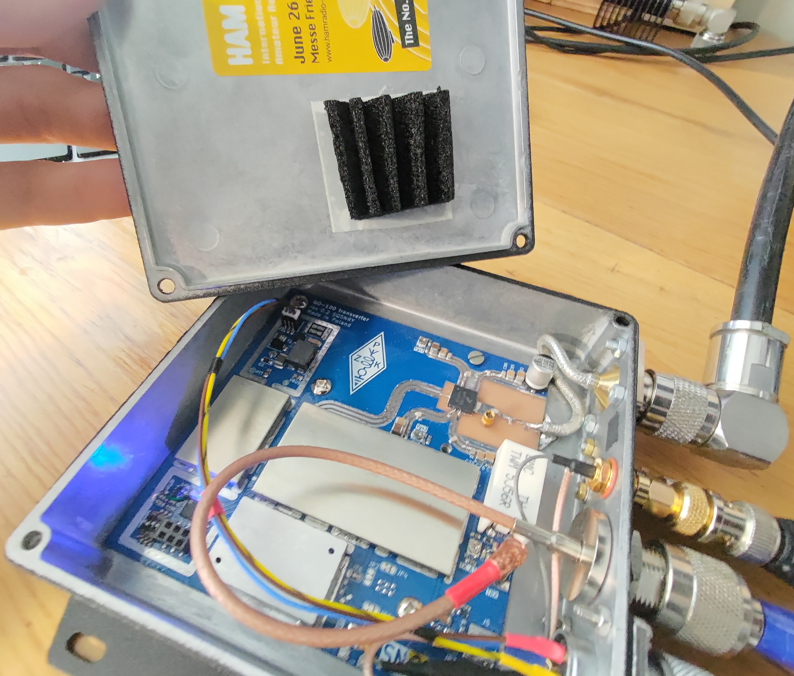
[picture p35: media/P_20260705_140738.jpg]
EMC absorber installed
<td></td>
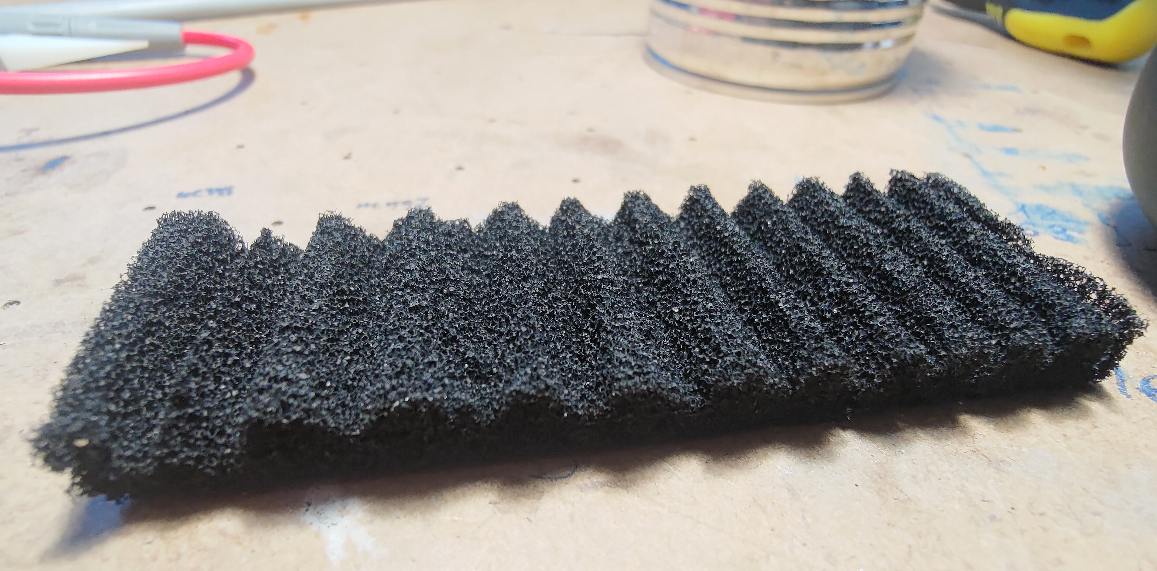
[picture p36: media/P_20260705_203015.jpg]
EMC absorber completed
<td></td>
</tr>
</table>

### Development and testing

<table>
<tr>
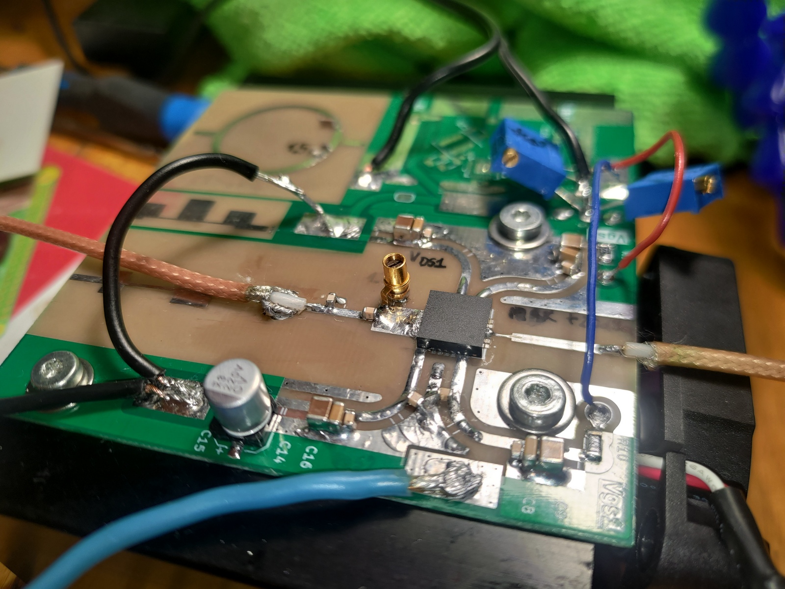
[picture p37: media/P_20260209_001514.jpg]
RF section prototype
<td></td>
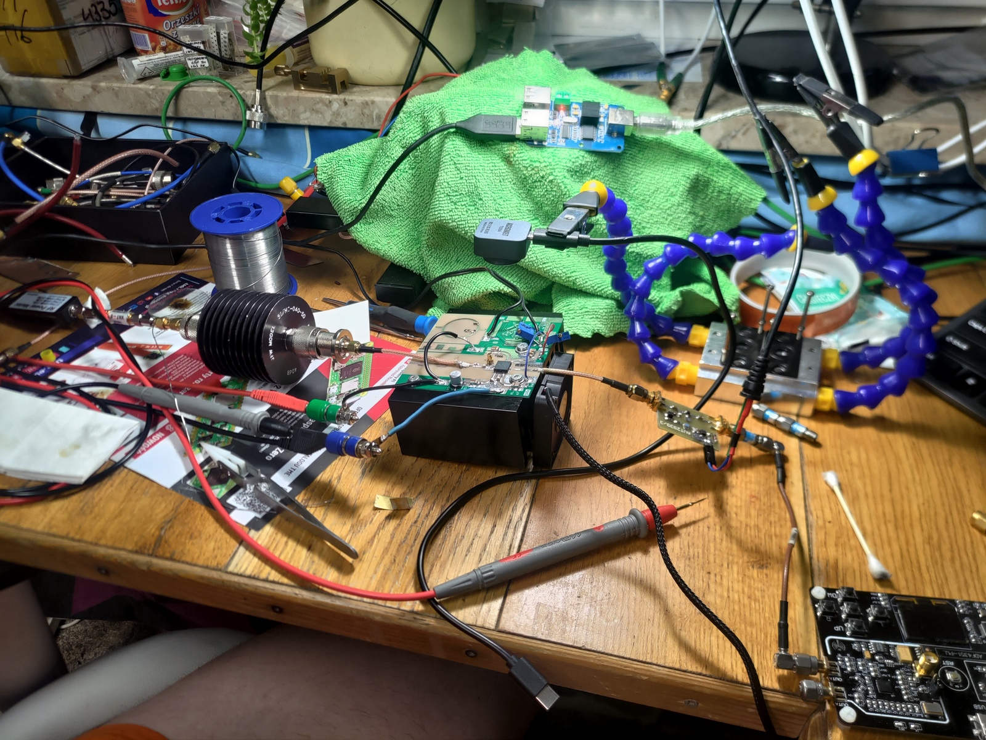
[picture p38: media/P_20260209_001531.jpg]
multi-board bench integration
<td></td>
</tr>
<tr>
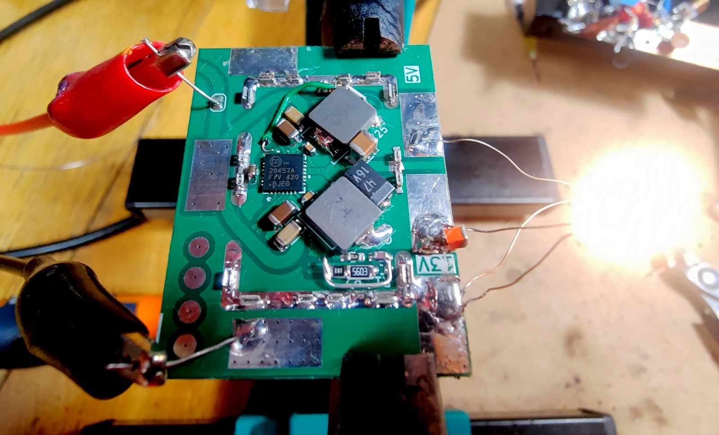
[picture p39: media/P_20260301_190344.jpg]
submodule PCB probing
<td></td>
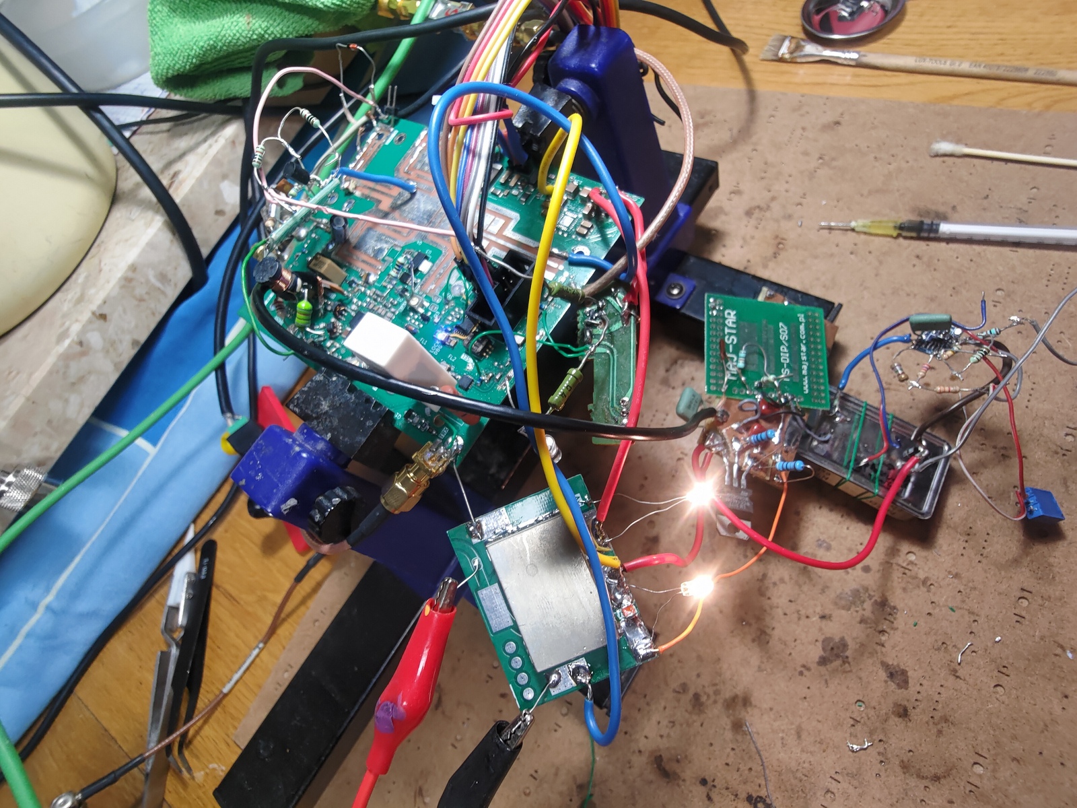
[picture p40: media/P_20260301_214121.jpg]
complex integration wiring
<td></td>
</tr>
<tr>
<td>early prototype debugging</td>
<td>v0.1 bench test</td>
</tr>
<tr>
<td>v0.1 test setup with instruments</td>
<td>PCB in helping hands during assembly</td>
</tr>
<tr>
<td>power supply IC close-up</td>
<td>C88<br><em>a cheap C88 (ordinary ceramic instead of ATC porcelain one)</em></td>
</tr>
</table>

### Measurements

<table>
<tr>
<td>test attenuator controller</td>
<td>bench integration</td>
</tr>
</table>

## Measurements - TX & RX paths

### TX mixer-to-driver-out, LDMOS gain

<table>
<tr>
<td>TX IF chain S21</td>
<td>PA S21</td>
</tr>
</table>

### LO, upper sideband, image, and 2nd harmonic levels

<table>
<tr>
<td>Output spectrum — LO leakage</td>
<td>Output spectrum — image frequency</td>
</tr>
<tr>
<td>Output spectrum — 2nd harmonic</td>
<td></td>
</tr>
</table>

### TRX port

<table>
<tr>
<td align="center">TX port, s11<br><em>TRX port on TX, s11</em></td>
<td align="center">RX port, s11<br><em>TRX port on RX, s11</em></td>
</tr>
</table>

> **⚠️ Note:** TX SWR on 23cm is high. Only RX has been tested and confirmed on this band. Proper TX 23cm testing is in progress — it may work with ALC-limited power from your transceiver.

### RF filtering

two 739MHz filters cascaded incl. balun loss
*two 739MHz filters cascaded incl. balun loss*

wideband RX characteristics from F socket to mixer incl. the high-pass filter input
*wideband RX characteristics from F socket to mixer incl. the high-pass filter. No shielding of IF Unit.*

### TCVCXO output spectrum

TCXO output spectrum

## Acknowledgements

- **SP5E Krzysztof** — for the original idea and other discussions
- **SQ6QV Tomasz** — for consultation
- **Colleagues from Radio Club in DOK Ursynów** — for countless discussions

## License

All source code, hardware design files, and documentation are publicly available — schematics, PCB layout, and firmware can be freely studied, built, and modified for personal and amateur radio use. This project is dual-licensed by component, and **commercial use of any part of it is not permitted**:

| Component | License |
|---|---|
| Firmware (`src/`, excluding bundled vendor drivers) | [GPL v2 + commercial exception](LICENSE-CODE) |
| Hardware design (`hw-trv/`, `hw-companion-box/`), manual, docs/media | [CC BY-NC-SA 4.0](LICENSE-HARDWARE) |

See [LICENSE](LICENSE) for the full overview. Third-party code bundled
under `src/Drivers/` (ST's STM32 HAL drivers and ARM's CMSIS headers)
keeps its own original license terms.

`src/Core/Src/rffc5071.c`, `src/Core/Src/rffc5071_spi.c`, and associated
headers are derived from [HackRF](https://github.com/greatscottgadgets/hackrf)
by [Great Scott Gadgets](https://greatscottgadgets.com/) and Jared Boone,
licensed under [GPL v2](https://www.gnu.org/licenses/old-licenses/gpl-2.0.html).

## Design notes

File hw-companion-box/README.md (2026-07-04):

# Companion Box

Auxiliary unit for the QO-100 transverter, providing:

- 13.8V to 28V voltage boost for powering the transverter from a standard 13.8V shack supply
- PTT combiner: mixes PTT signal with RF on the coax line to the transverter

The built-in buzzer sounds an audible alert when the PTT line is unplugged — this is to notify the operator of a disconnected PTT cable before transmitting.

See [schematics](sch_companion_box.pdf) for details.

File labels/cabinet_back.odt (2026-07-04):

\

rev 0.2 SQ5NRY

S/N:

Made in Poland

DC+PTT

28V (13.8V)

1.1A

rev 0.2 SQ5NRY

S/N:

Made in Poland

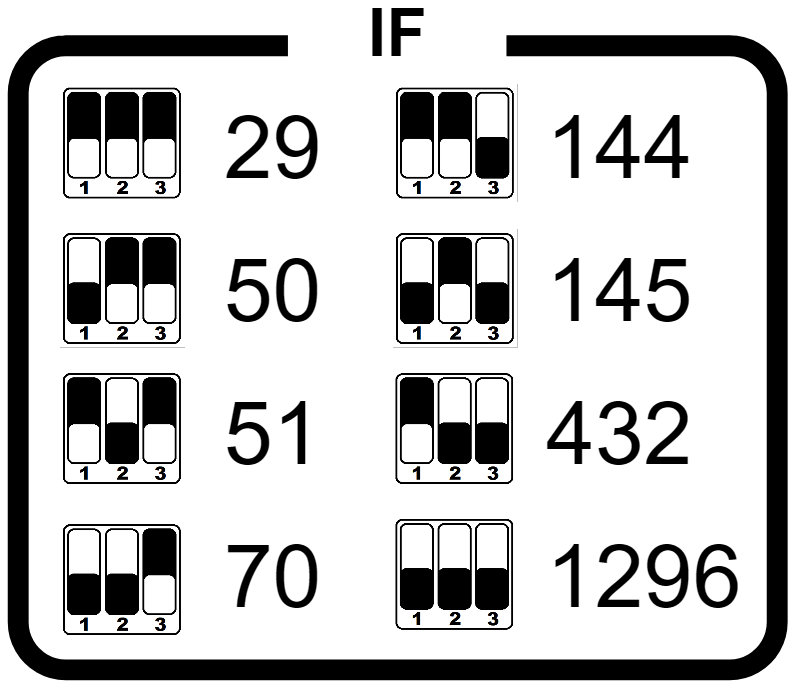
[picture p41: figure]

IF

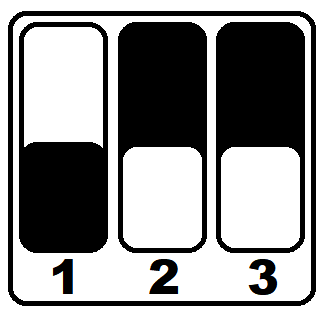
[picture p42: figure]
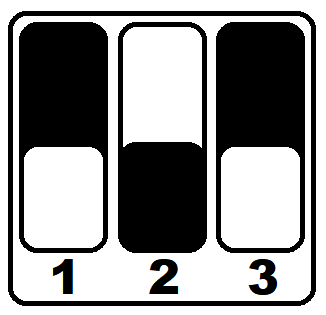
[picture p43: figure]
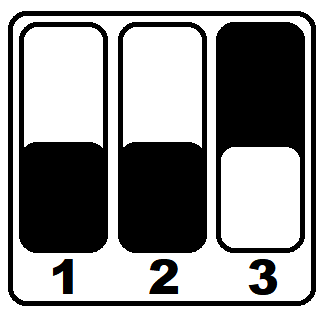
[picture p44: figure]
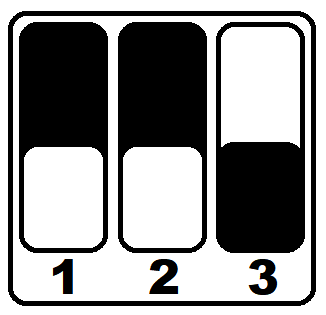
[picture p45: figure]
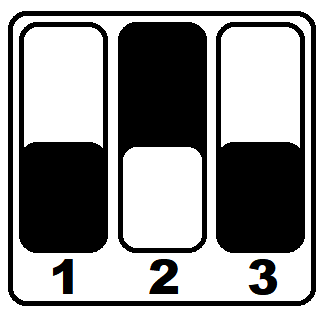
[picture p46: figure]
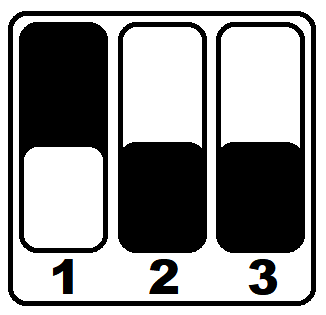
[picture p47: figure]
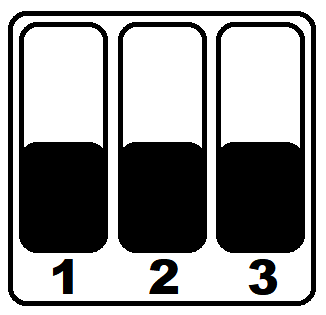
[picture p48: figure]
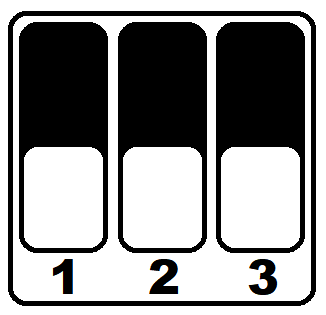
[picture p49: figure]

29

50

51

70

144

145

432

1296

S

rev 0.2 SQ5NRY

S/N:

Made in Poland

S/N:

rev 0.2 SQ5NRY

S/N:

Made in Poland

rev 0.2 SQ5NRY

Made in Poland

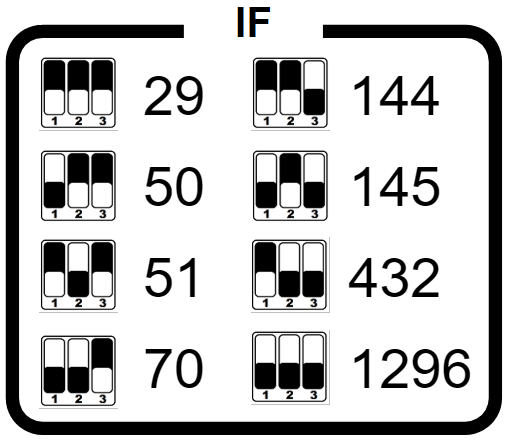
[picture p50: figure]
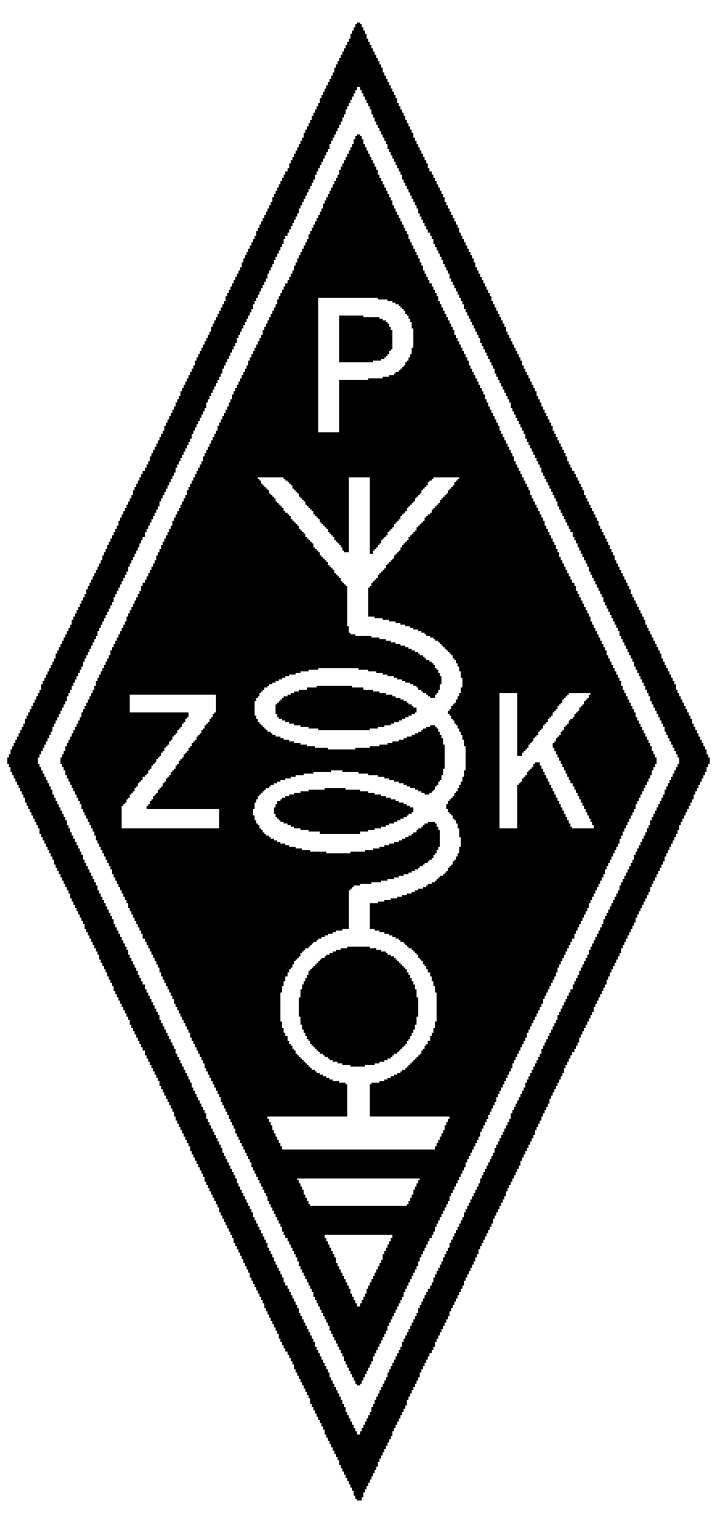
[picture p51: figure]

QO-100 transverter

28V (13.8V)

1.1A

max 5W

RX ext

ref out

TX

2.4G

TRX

LNB

DC

PTT

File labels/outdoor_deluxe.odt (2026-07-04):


QO-100 transverter

28V (13.8V)

1.1A

max 5W

TX

2.4G

DC

PTT

RX ext

ref out

TRX

LNB

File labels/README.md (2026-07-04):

# Labels

Label artwork for the QO-100 transverter enclosures (front panel, rear panel, outdoor versions).

## PZK Logo

The label artwork includes the logo of [PZK — Polski Związek Krótkofalowców](https://www.pzk.org.pl/)
(Polish Amateur Radio Union). The PZK logo is the property of PZK and is used in this project
with PZK's permission.

Anyone reproducing these labels must either obtain their own permission from PZK before using
their logo, or replace it with their own club or personal artwork.

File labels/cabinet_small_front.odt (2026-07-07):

\

QO-100 transverter

TX 2.4G


rev 0.2 SQ5NRY

S/N:

Made in Poland

rev 0.2 SQ5NRY

S/N:

Made in Poland

rev 0.2 SQ5NRY

S/N:

Made in Poland

rev 0.2 SQ5NRY

S/N:

Made in Poland

rev 0.2 SQ5NRY

S/N:

Made in Poland

rev 0.2 SQ5NRY

S/N:

Made in Poland

rev 0.2 SQ5NRY

S/N:

Made in Poland

rev 0.2 SQ5NRY

S/N:

Made in Poland

max 5W

rev 0.2 SQ5NRY

S/N:

Made in Poland

rev 0.2 SQ5NRY

S/N:

Made in Poland

rev 0.2 SQ5NRY

S/N:

Made in Poland

rev 0.2 SQ5NRY

S/N:

Made in Poland

rev 0.2 SQ5NRY

S/N:

Made in Poland

rev 0.2 SQ5NRY

S/N:

Made in Poland

rev 0.2 SQ5NRY

S/N:

Made in Poland

rev 0.2 SQ5NRY

S/N:

Made in Poland

TRX

LNB

RX ext

ref out


rev 0.2 SQ5NRY

S/N:

Made in Poland

rev 0.2 SQ5NRY

S/N:

Made in Poland

rev 0.2 SQ5NRY

S/N:

Made in Poland

rev 0.2 SQ5NRY

S/N:

Made in Poland

rev 0.2 SQ5NRY

S/N:

Made in Poland

rev 0.2 SQ5NRY

S/N:

Made in Poland

rev 0.2 SQ5NRY

S/N:

Made in Poland

rev 0.2 SQ5NRY

S/N:

Made in Poland

rev 0.2 SQ5NRY

S/N:

Made in Poland

rev 0.2 SQ5NRY

S/N:

Made in Poland

rev 0.2 SQ5NRY

S/N:

Made in Poland

rev 0.2 SQ5NRY

S/N:

Made in Poland

rev 0.2 SQ5NRY

S/N:

Made in Poland

rev 0.2 SQ5NRY

S/N:

Made in Poland

rev 0.2 SQ5NRY

S/N:

Made in Poland

rev 0.2 SQ5NRY

S/N:

Made in Poland

28V (13.8V)

1.1A

DC

PTT

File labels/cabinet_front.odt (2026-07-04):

\


QO-100 transverter

TX 2.4G

max 5W

TRX

LNB

RX ext

ref out

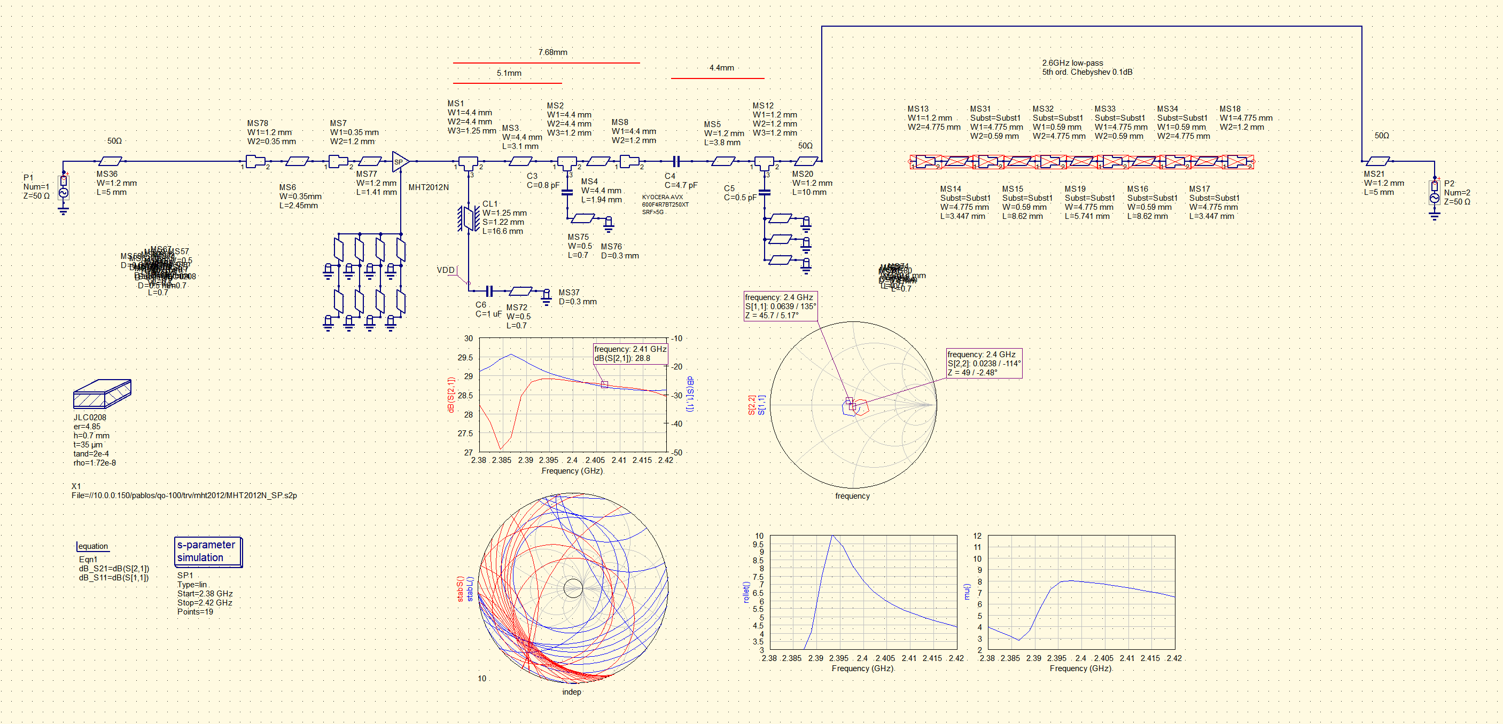
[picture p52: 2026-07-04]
hw-trv/qucs-project/pa_schematics.png

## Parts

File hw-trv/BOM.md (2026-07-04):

# Bill of Materials — QO-100 Transverter (hw-trv)

Total cost at order quantity of 10 units: 871PLN **(~200EUR)** (EUR/PLN ≈ 4.36)

Prices are gross (with VAT), in PLN.

## Capacitors

| Qty | Value / Part | Description | Total PLN |
|-----|---|---|---|
| 1 | 22n | Feedthrough capacitor NFM41CC223 | 1.48 |
| 1 | 22n | Feedthrough capacitor NFM39R12C223 | 1.23 |
| 2 | 1n | MLCC 0805 | 0.37 |
| 2 | 1n | MLCC 0603 | 0.37 |
| 10 | 10n | MLCC 0603 | 1.23 |
| 2 | 100 | MLCC 0603 | 0.25 |
| 1 | 10n | MLCC 0603 | 0.12 |
| 1 | 1n | MLCC 0603 | 0.12 |
| 1 | 15p | MLCC 0603 | 0.12 |
| 1 | 1n | MLCC 0603 | 0.25 |
| 11 | 100n | MLCC 0603 | 1.35 |
| 1 | 180 | MLCC 0603 | 0.12 |
| 1 | 8p2 | MLCC 0603 | 0.12 |
| 2 | 330 | MLCC 0603 | 0.25 |
| 1 | 1n | MLCC 0603 | 0.12 |
| 7 | 33 | MLCC 0603 | 0.86 |
| 10 | 100 | MLCC 0603 | 1.23 |
| 4 | 100n | MLCC 0603 | 0.49 |
| 1 | 0.8 | 0402 | 0.12 |
| 1 | 4.7u | 1206 | 0.62 |
| 3 | 10u | 1210 | 1.85 |
| 4 | 10u | GRM32ER61H106KA12L, 1210 | 4.92 |
| 3 | 470n | 0603 | 0.37 |
| 1 | 1.8 | 0603 | 0.12 |
| 2 | 3n3 | MLCC 0603 | 0.25 |
| 1 | 12 | 0603 | 0.12 |
| 2 | 4.7 | 0603 | 0.25 |
| 2 | 1u | 0603 | 0.25 |
| 4 | 100n | GRM32NR72A104KA01B, 1210 | 7.38 |
| 1 | 4.7u | Tantalum B | 1.23 |
| 2 | 470 | MLCC 0603 | 0.25 |
| 1 | 220uF | Aluminium electrolytic, 6.3x5.8 | 3.08 |
| 1 | 1.3 | ATC600F, 0805 | 5.90 |
| 1 | 4.7 | ATC600F4R7BT250XT, 0805 | 5.41 |
| 1 | 0.5+1.3 | ATC600F0R5BT250XT, 0805 | 5.41 |
| 1 | 100n | MLCC 0805 | 0.18 |
| 2 | 22u | GRM31CR71A226KE15, 1206 | 3.69 |
| 2 | 100n | MLCC 0805 | 0.37 |
| 2 | 100n | MLCC 1206 | 0.74 |
| 2 | 4.7u | GMK316AB7475MLHT, 1206 | 1.23 |
| 2 | 100n | MLCC 0603 | 0.25 |
| 1 | 4.7u | CL10A475KO8NNNC, 0603 | 0.25 |
| 1 | 22u | 1206 | 0.62 |
| 1 | 100n | MLCC 0805 | 0.18 |

## Diodes and LEDs

| Qty | Value / Part | Description | Total PLN |
|-----|---|---|---|
| 1 | SMAJ30CA | 400W bidirectional TVS 30V, SMA | 0.98 |
| 1 | SMAJ15CA-TP | 400W bidirectional TVS 15V, SMA | 1.11 |
| 1 | BAT54WS | 75V 0.15A fast switching, SOD-123 | 0.49 |
| 1 | BAR64 | BAR6402VH6327XTSA1, SOD-523 | 0.49 |
| 1 | INFO | LED green, 0805 | 0.25 |
| 2 | BAV99 | High-speed switching diodes, SOT-23 | 0.49 |
| 1 | LOCK | LED blue, 0805 | 0.49 |

## Fuses

| Qty | Value / Part | Description | Total PLN |
|-----|---|---|---|
| 1 | 1.5A | SMDH2920B150TF, 2920 | 1.23 |
| 1 | 100mA | MICROSMD010F-2, 1210 | 1.72 |
| 1 | 500mA | MF-NSMF025/30X-2, 1206 | 1.72 |

## Inductors and Filters

| Qty | Value / Part | Description | Total PLN |
|-----|---|---|---|
| 1 | ECMS1V0905-222-R | Common mode choke, TDK ACM7060 | 3.32 |
| 2 | TA0532A | 2400–2550 MHz BPF 50Ω, FV1206-4 | 36.90 |
| 5 | FB | Ferrite bead 2518121217Y3, 1812 | 6.15 |
| 1 | 1u + 390n | PE-1008CD102JTT + C2520C-R39J, 0805 | 1.48 |
| 1 | 4.7u | MLF2012A4R7KT, 0805 | 0.37 |
| 2 | FB | Ferrite bead, 0402 | 0.49 |
| 2 | 742792693 | BK1608HM102TL, 0603 | 1.97 |
| 1 | 120n | Inductor 0805 | 0.49 |
| 1 | 10n | Inductor 0603 | 0.49 |
| 1 | 180n | Inductor 0805 | 0.49 |
| 1 | 820n | 7447610282, 0603 | 1.35 |
| 1 | 220n | HBWS1608-R22 SRF=1GHz 200mA, 0603 | 0.62 |
| 1 | FB | BLM21PG221SN1, Walsin WLFM201209x | 0.37 |
| 1 | 3.3n | 1 turn 3mm, 0.3mm silver-plated wire (hand wound) | 0.12 |
| 2 | 2.2u | HCMA0703-2R2-R | 6.15 |
| 7 | 5.6 | ATC600F5R6BT250XT, 0805 | 41.33 |
| 2 | TA1862A | 869 MHz SAW BPF, 6-pin DCC6C | 36.90 |

## Transistors

| Qty | Value / Part | Description | Total PLN |
|-----|---|---|---|
| 1 | BC848 | 0.1A 30V NPN, SOT-23 | 0.20 |
| 1 | BC848B | 0.1A 30V NPN, SOT-23 | 0.20 |
| 2 | BSS84P | BSS84PH6327XTSA2 PMOS, SOT-23 | 1.48 |
| 1 | MMBT3904 | 0.2A 40V NPN, SOT-23 | 0.20 |

## Resistors

| Qty | Value / Part | Description | Total PLN |
|-----|---|---|---|
| 4 | 4.7k | 0603 | 0.25 |
| 3 | 100k | 0603 | 0.18 |
| 5 | 10k | 0603 | 0.31 |
| 2 | 47k | 0603 | 0.12 |
| 4 | 1k | 0603 | 0.25 |
| 1 | 39k | 0603 | 0.06 |
| 2 | 22k | 0603 | 0.12 |
| 1 | 56 | 5W, THT | 3.69 |
| 1 | 1k5 | 0603 | 0.06 |
| 2 | 470 | 0603 | 0.12 |
| 3 | 220 | 0603 | 0.18 |
| 1 | 56 | 0603 | 0.06 |
| 1 | 51k 1% | 0603 | 0.06 |
| 1 | 6.8k | 0603 | 0.06 |
| 1 | 15k | 0603 | 0.06 |
| 1 | 2.7k | 0603 | 0.06 |
| 1 | 100 | 0603 | 0.06 |
| 6 | 270 | 0603 | 0.37 |
| 3 | 18 | 0603 | 0.18 |
| 1 | 330 | 0603 | 0.06 |
| 2 | 2k2 | 0603 | 0.12 |
| 2 | 22k 1% | 0805 | 0.25 |
| 1 | 121.2k | 0603 | 0.12 |
| 1 | 2k2 | TC33x trimmer | 0.98 |
| 1 | 2k2 | 3314J trimmer | 5.90 |
| 2 | 5k | TC33X trimmer | 1.97 |

## Integrated Circuits

| Qty | Value / Part | Description | Total PLN |
|-----|---|---|---|
| 1 | RFFC2071TR13 | 85–2700 MHz RF synthesizer/VCO with integrated mixer | 79.95 |
| 1 | MHT2012NT1 | 2450 MHz 12.5W LDMOS RF power amplifier, 28V, PQFN 8x8 | 88.56 |
| 1 | SKY66292-11 | RF PA driver, QFN16 5x5 | 36.90 |
| 1 | ETC1.6-4-2-3TR | RF transformer | 9.35 |
| 1 | TC4-19+ | RF transformer (Mini-Circuits) | 12.30 |
| 2 | MABACT0039 | RF component (Mini-Circuits) | 22.14 |
| 1 | STM32L011D4P6TR | ARM Cortex-M0+ MCU 16KB flash 2KB RAM 32MHz, TSSOP-14 | 4.31 |
| 1 | 74LVC2G17 | Dual Schmitt-trigger buffer, SC70-6 | 0.49 |
| 1 | TPS73633DBVRG4 | 400mA 3.3V LDO, SOT-23-5 | 8.86 |
| 1 | LP2985-18DBVR | 150mA 1.8V low-noise LDO, SOT-23-5 | 1.35 |
| 1 | MIC5219-3.0YMM | 500mA 3.0V LDO, MSOP-8 | 5.54 |
| 2 | TLV74130PDBVR | 200mA 1.2V LDO, SOT-23-5 | 0.98 |
| 1 | MAX20457ATIF/VY+ | DC-DC converter | 22.14 |
| 1 | L78L09ACUTR | 100mA 9V linear regulator, SOT-89 | 1.23 |
| 1 | LFTVXO076346 25MHz | HCMOS TCVCXO 25 MHz | 76.26 |

## Switches and Connectors

| Qty | Value / Part | Description | Total PLN |
|-----|---|---|---|
| 1 | SW_DIP_x03 | 3-position DIP slide switch 416131160803 | 3.69 |
| 1 | VCC+PTT | Molex 87437-0363 connector | 3.69 |
| 1 | TRX | N-type panel socket | 14.76 |
| 1 | SWD ISP | 2x3 pin header 2.54mm | 1.85 |
| 1 | RX_OUT / 25M_REF | N-type vertical SMA | 14.76 |
| 1 | LNB | F-type panel socket | 12.30 |
| 1 | TX | N-type flange mount panel socket | 18.45 |

## Mechanical and Assembly

| Qty | Value / Part | Description | Total PLN |
|-----|---|---|---|
| 1 | WF16 Weipu 3-pin | Panel socket (power + PTT) | 22.14 |
| 1 | WF16 Weipu 3-pin | Mating plug | 17.22 |
| 1 | 0.5m 0.25 LGY | Cable assembly | 1.23 |
| 1 | Hammond ALU outdoor | Aluminium enclosure | 86.10 |
| 1 | PCB | JLCPCB, blue, 10cm×10cm | 10.09 |
| 0.1 | PCB stencil | JLCPCB | 5.54 |
| 0.05 | Solder paste | Sn63/Pb37 XG-50 Mechanic 35g | 3.08 |
| 17 | M3 screws | 1/1.5/3/6 mm lengths | 2.09 |
| 1 | HYLOMAR | Sealing compound | 0.25 |
| 1 | Gore-tex vent | Moisture vent cap | 0.62 |
| 1 | Label sheet | A4 sticker, front & back laser print | 0.62 |
| 1 | EMI shield — SMPS | 30×20 mm | 6.15 |
| 1 | EMI shield — IF unit | 56×30 mm | 9.84 |
| 1 | EMI shield — TCXO | 30×20 mm | 18.45 |
| 1 | Heat pipe | Flat 90 mm | 24.60 |
| 1 | TCXO mounting | Polyester tape + foam fitting | 0.62 |
| 1 | Thermal pads | ARCTIC TP-3 | 1.23 |
| 1 | Thermal grease | Generic | 0.62 |

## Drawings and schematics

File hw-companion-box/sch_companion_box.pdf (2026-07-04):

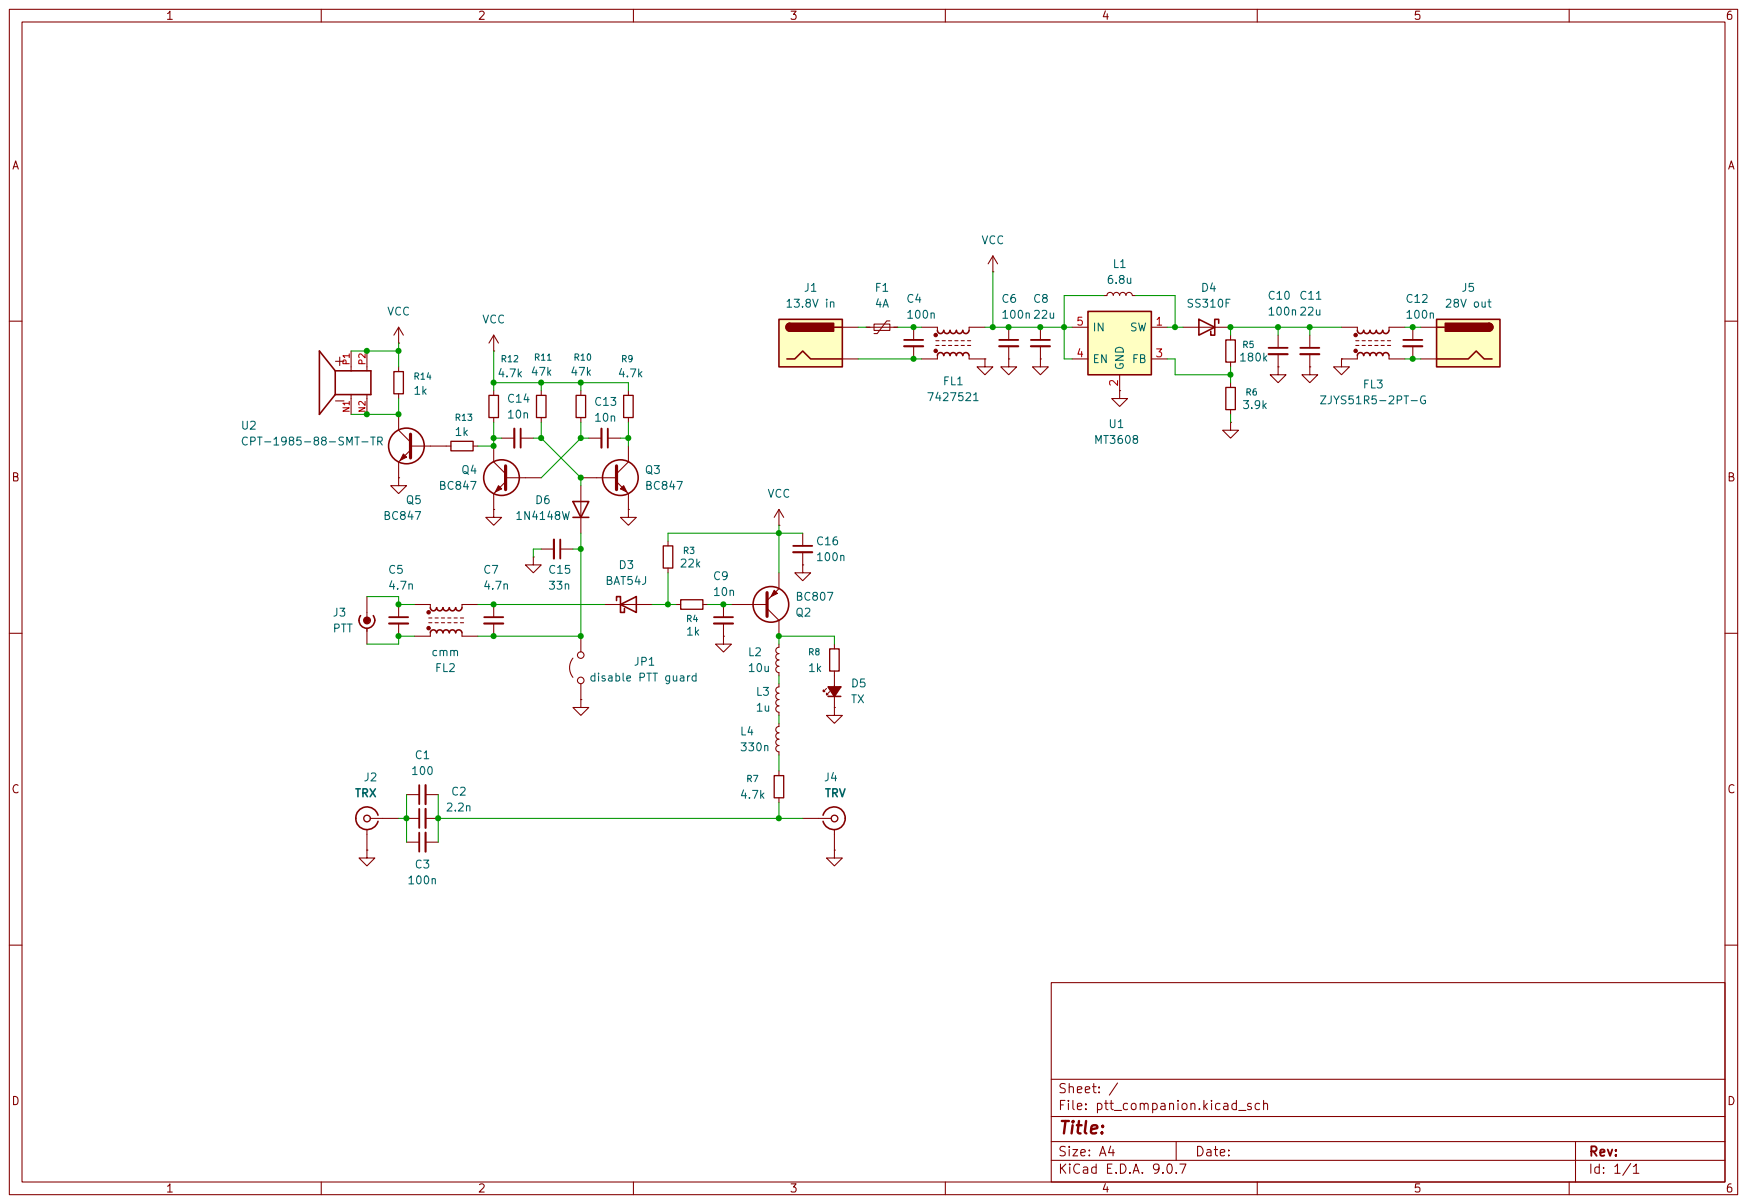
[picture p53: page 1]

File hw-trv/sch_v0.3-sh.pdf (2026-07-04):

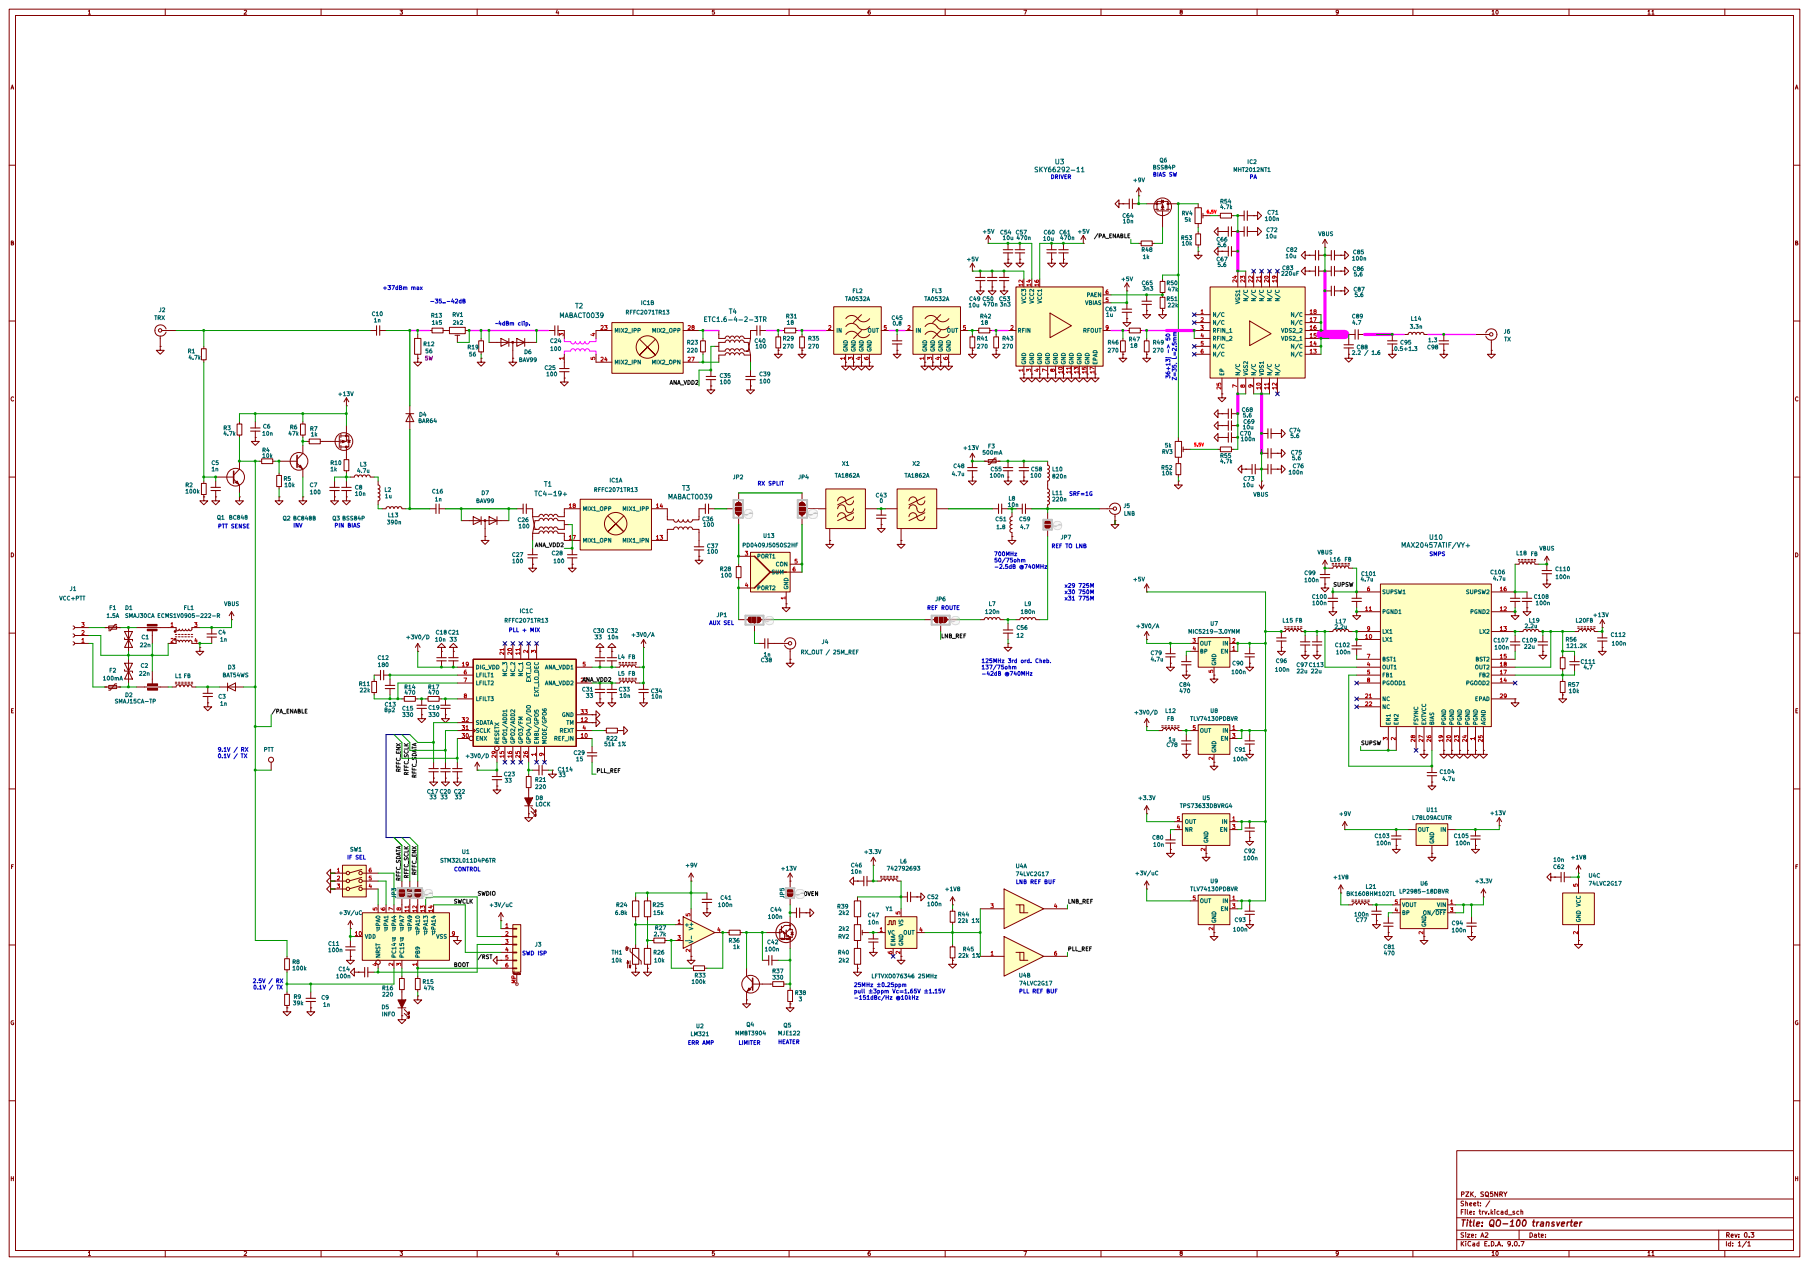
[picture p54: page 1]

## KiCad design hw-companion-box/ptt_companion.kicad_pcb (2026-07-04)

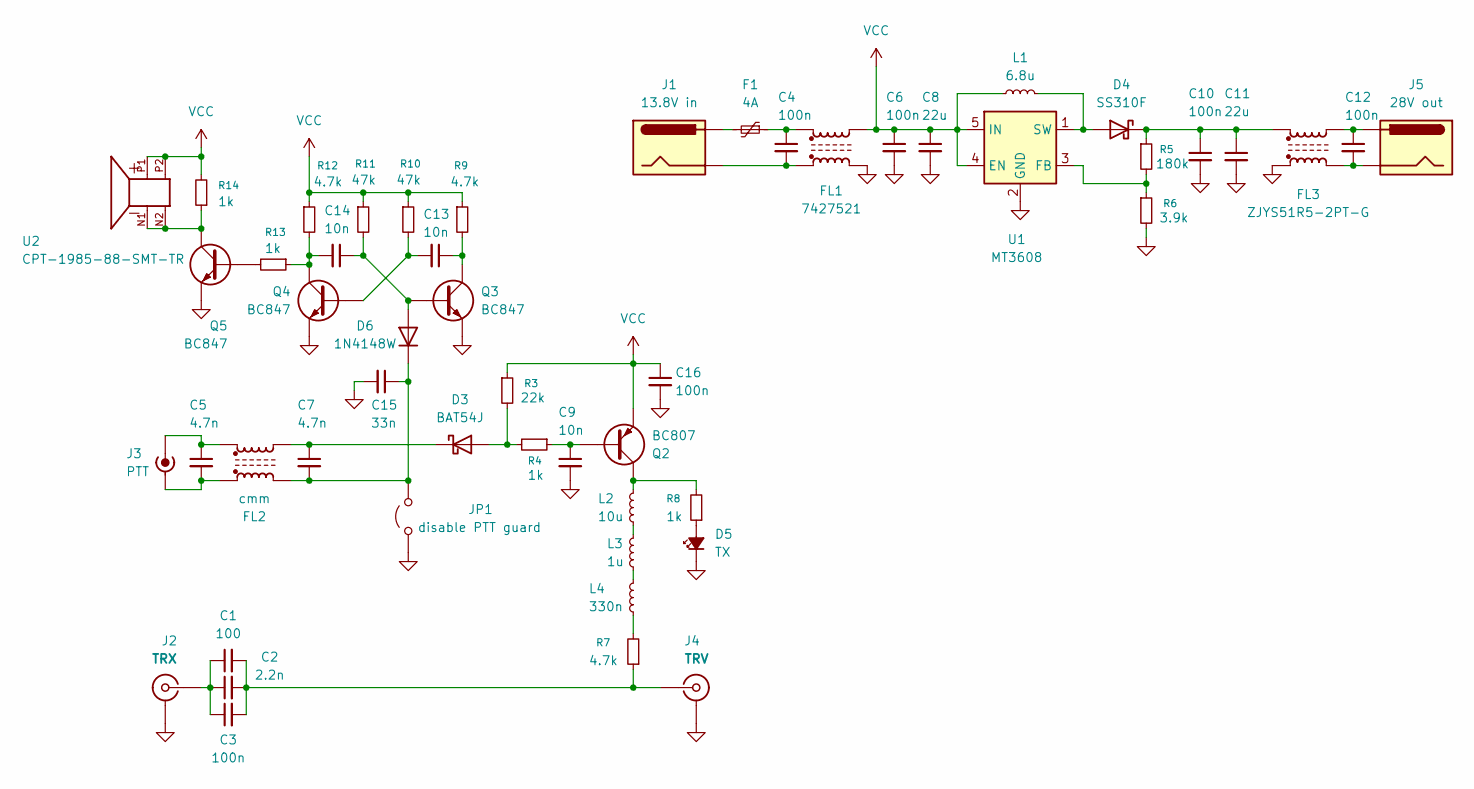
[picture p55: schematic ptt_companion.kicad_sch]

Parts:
C1: 100; C_0805_2012Metric_Pad1.18x1.45mm_HandSolder; Voltage 250V
C2: 2.2n; C_0805_2012Metric_Pad1.18x1.45mm_HandSolder; Voltage 250V
C3: 100n; C_0805_2012Metric_Pad1.18x1.45mm_HandSolder; Voltage 250V
C4, C6, C10, C12: 100n; C_0805_2012Metric_Pad1.18x1.45mm_HandSolder
C5, C7: 4.7n; C_0603_1608Metric_Pad1.08x0.95mm_HandSolder
C8, C11: 22u; C_1206_3216Metric_Pad1.33x1.80mm_HandSolder
C9, C13, C14: 10n; C_0603_1608Metric_Pad1.08x0.95mm_HandSolder
C15: 33n; C_0603_1608Metric_Pad1.08x0.95mm_HandSolder
C16: 100n; C_0603_1608Metric_Pad1.08x0.95mm_HandSolder
D3: BAT54J; D_SOD-323F
D4: SS310F; D_SMA_Handsoldering
D5: TX; LED_D5.0mm_Clear
D6: 1N4148W; D_SOD-123
F1: 4A; Fuse_2920_7451Metric_Pad2.10x5.45mm_HandSolder
FL1: 7427521; L_CommonMode_Delevan_4222
FL2: cmm; L_CommonMode_Wurth_WE-CNSW-1206
FL3: ZJYS51R5-2PT-G; L_CommonModeChoke_TDK_ACM7060
J1: 13.8V in; AMASS_XT30U-F_1x02_P5.0mm_Vertical
J2: TRX; MountingHole_5.3mm_M5_Pad_Via
J3: PTT; AMASS_XT30U-F_1x02_P5.0mm_Vertical
J4: TRV; MountingHole_5.3mm_M5_Pad_Via
J5: 28V out; AMASS_XT30U-F_1x02_P5.0mm_Vertical
JP1: disable PTT guard; SolderJumper-2_P1.3mm_Open_TrianglePad1.0x1.5mm
L1: 6.8u; L_Ferrocore_DLG-0403
L2: 10u; L_0805_2012Metric
L3: 1u; L_0805_2012Metric
L4: 330n; L_0805_2012Metric
Q2: BC807; SOT-23
Q3, Q4, Q5: BC847; SOT-23
R3: 22k; R_0603_1608Metric_Pad0.98x0.95mm_HandSolder
R4, R8, R13, R14: 1k; R_0603_1608Metric_Pad0.98x0.95mm_HandSolder
R5: 180k; R_0603_1608Metric_Pad0.98x0.95mm_HandSolder
R6: 3.9k; R_0603_1608Metric_Pad0.98x0.95mm_HandSolder
R7, R9, R12: 4.7k; R_0603_1608Metric_Pad0.98x0.95mm_HandSolder
R10, R11: 47k; R_0603_1608Metric_Pad0.98x0.95mm_HandSolder
U1: MT3608; SOT-23-6
U2: CPT-1985-88-SMT-TR; XDCR_CPT-1985-88-SMT-TR; PARTREV 1.0

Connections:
GND: C6.2, C8.2, C9.2, C10.2, C11.2, C15.2, C16.2, D5.1 (K), FL1.4, FL3.1, J2.2 (Ext), J4.2 (Ext), JP1.1 (A), Q3.2 (E), Q4.2 (E), Q5.2 (E), R6.2, U1.2 (GND)
unnamed: C4.1, F1.1, FL1.1
unnamed: C4.2, FL1.3, J1.2
unnamed: C12.1, FL3.4, J5.1
unnamed: C12.2, FL3.2, J5.2
unnamed: D3.2 (A), R3.2, R4.2
unnamed: C7.1, D3.1 (K), FL2.4
unnamed: D4.2 (A), L1.1, U1.1 (SW)
unnamed: C10.1, C11.1, D4.1 (K), FL3.3, R5.1
unnamed: D5.2 (A), R8.1
unnamed: C14.1, D6.2 (A), Q3.1 (B), R11.2
unnamed: C7.2, C15.1, D6.1 (K), FL2.2, JP1.2 (B)
unnamed: F1.2, J1.1
unnamed: C1.1, C2.1, C3.1, J2.1 (In)
unnamed: C5.2, FL2.1, J3.2 (Ext)
unnamed: C5.1, FL2.3, J3.1 (In)
unnamed: C1.2, C2.2, C3.2, J4.1 (In), R7.1
unnamed: L2.1, L3.2
unnamed: L3.1, L4.2
unnamed: L4.1, R7.2
unnamed: C9.1, Q2.1 (B), R4.1
unnamed: L2.2, Q2.3 (C), R8.2
unnamed: C13.1, Q3.3 (C), R9.2
unnamed: C13.2, Q4.1 (B), R10.2
unnamed: C14.2, Q4.3 (C), R12.2, R13.1
unnamed: Q5.1 (B), R13.2
unnamed: Q5.3 (C), R14.1, U2.N1, U2.N2
unnamed: R5.2, R6.1, U1.3 (FB)
VCC: C6.1, C8.1, C16.1, FL1.2, L1.2, Q2.2 (E), R3.1, R9.1, R10.1, R11.1, R12.1, R14.2, U1.4 (EN), U1.5 (IN), U2.P1, U2.P2

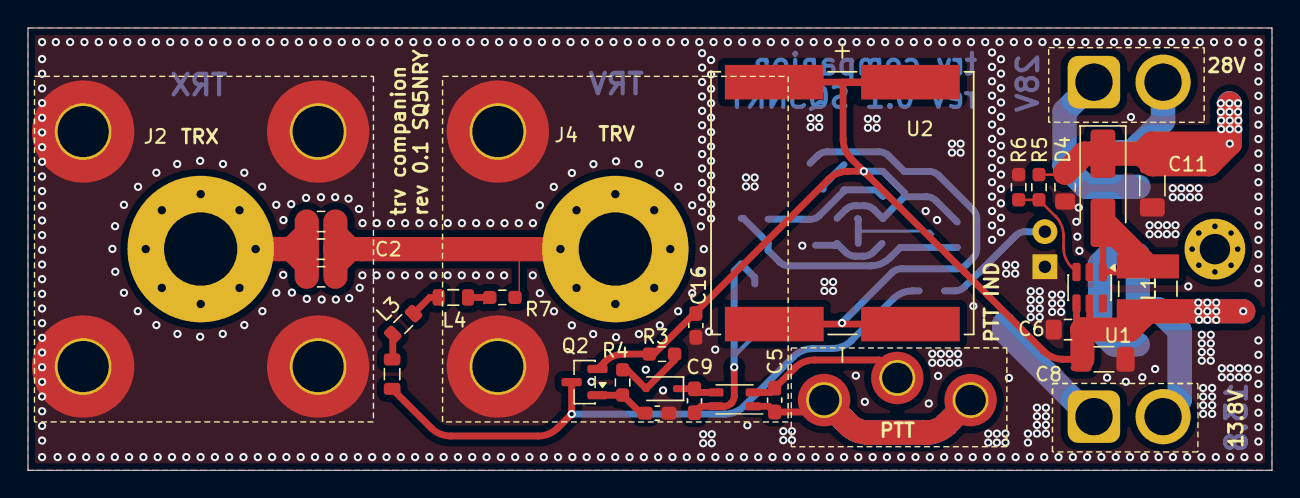
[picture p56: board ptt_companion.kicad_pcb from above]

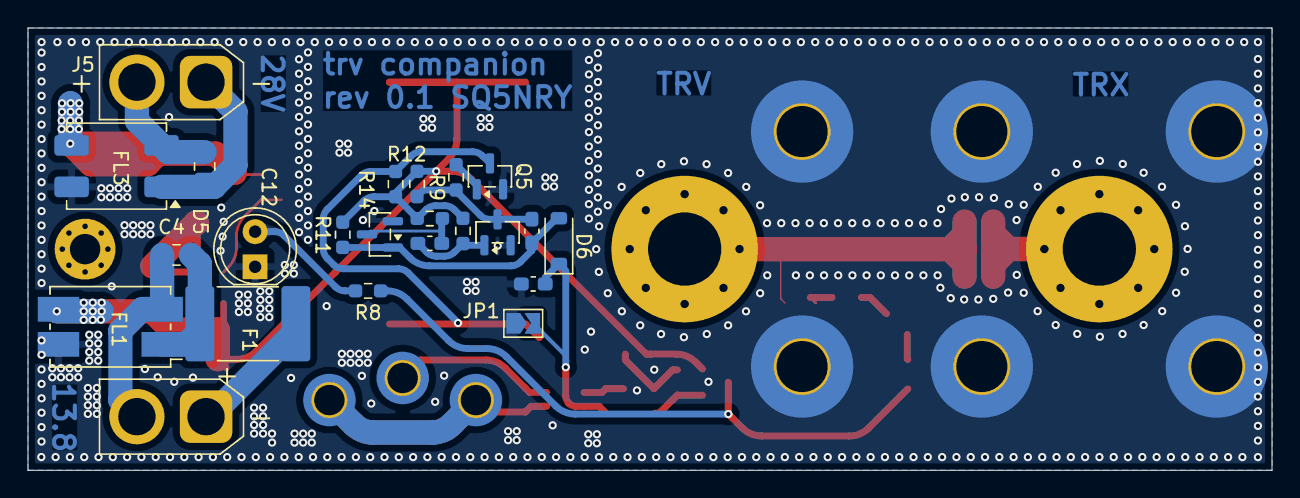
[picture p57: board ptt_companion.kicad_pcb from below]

Board: 2 copper layers, 90.0 x 32.0 mm, 51 parts (23 on the bottom side), 29 nets.

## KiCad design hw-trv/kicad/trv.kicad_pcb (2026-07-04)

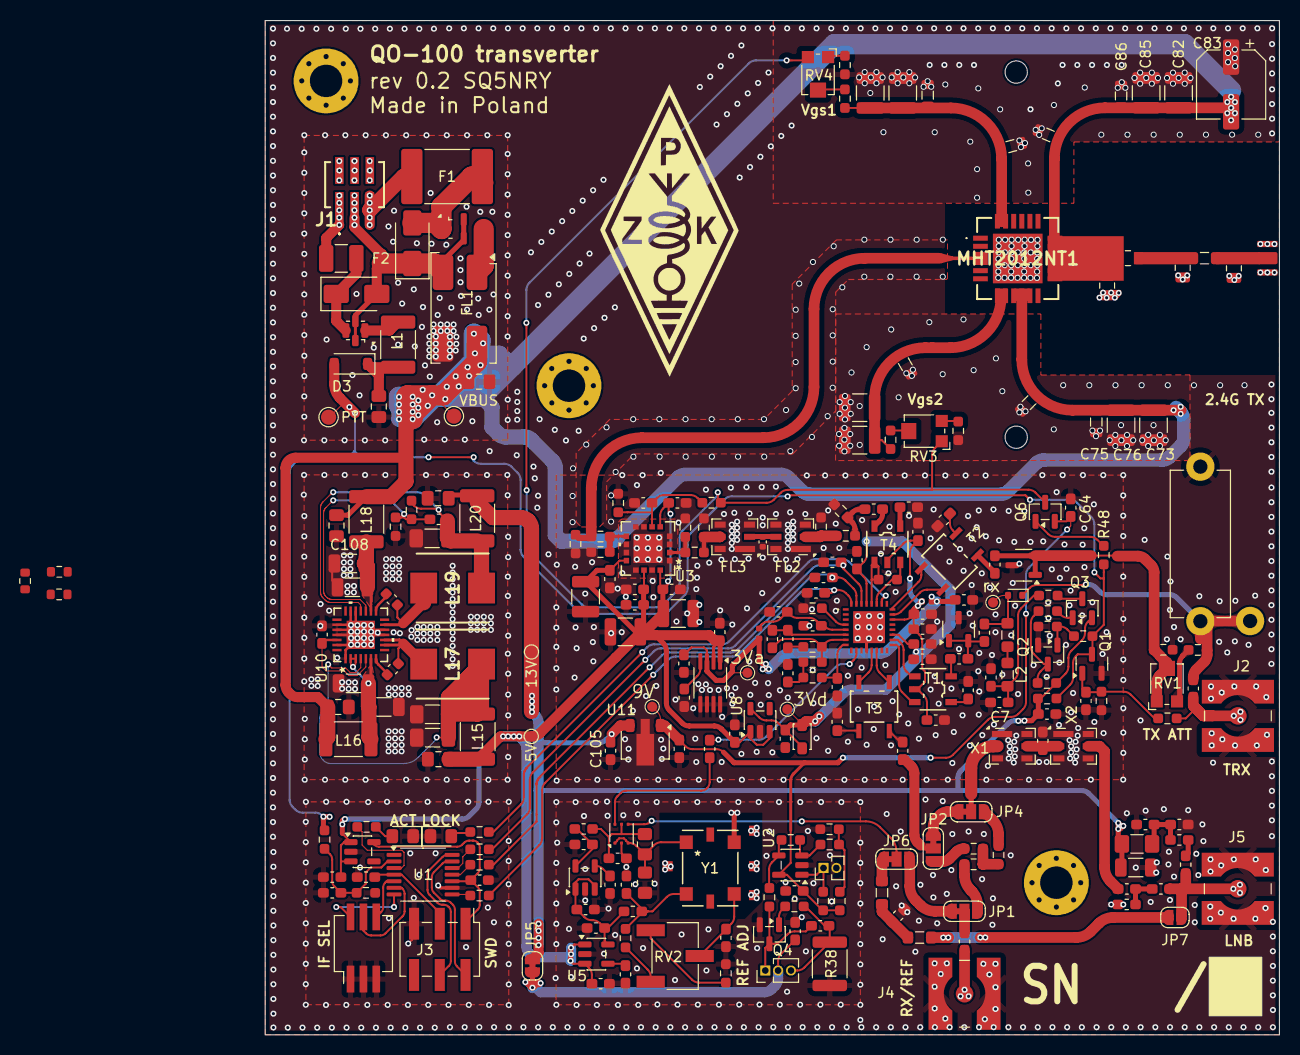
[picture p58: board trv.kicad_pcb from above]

Board: 2 copper layers, 100.0 x 100.0 mm, 255 parts (0 on the bottom side), 143 nets.

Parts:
3Va, 3Vd, 9V: (no value)
5V, 13V: TestPoint_Pad_D1.0mm
C1, C2: 22n; Filter_Mini-Circuits_FV1206
C3, C4: 1n; C_0805_2012Metric_Pad1.18x1.45mm_HandSolder
C5, C9, C10, C16, C29, C38: 1n; C_0603_1608Metric_Pad1.08x0.95mm_HandSolder
C6, C8, C18, C32, C33, C34, C46, C47, C62, C64, C80: 10n; C_0603_1608Metric_Pad1.08x0.95mm_HandSolder
C7: 100 *; C_0603_1608Metric_Pad1.08x0.95mm_HandSolder
C11, C14, C41, C42, C44, C52, C55, C77, C90, C91, C92, C93, C94, C103, C105: 100n; C_0603_1608Metric_Pad1.08x0.95mm_HandSolder
C12: 180; C_0603_1608Metric_Pad1.08x0.95mm_HandSolder
C13: 8p2; C_0603_1608Metric_Pad1.08x0.95mm_HandSolder
C15, C19: 330; C_0603_1608Metric_Pad1.08x0.95mm_HandSolder
C17, C20, C21, C22, C23, C30, C31: 33; C_0603_1608Metric_Pad1.08x0.95mm_HandSolder
C24, C25, C26, C27, C28, C35, C36, C37, C39, C40, C58: 100; C_0603_1608Metric_Pad1.08x0.95mm_HandSolder
C43: 0; C_0603_1608Metric_Pad1.08x0.95mm_HandSolder
C45: 1; C_0402_1005Metric
C48, C101, C106: 4.7u; C_1206_3216Metric
C49, C54, C60, C69, C72, C73, C82: 10u; C_1210_3225Metric
C50, C57, C61: 470n; C_0603_1608Metric_Pad1.08x0.95mm_HandSolder
C51: 1.8; C_0603_1608Metric_Pad1.08x0.95mm_HandSolder
C53, C65: 3n3; C_0603_1608Metric_Pad1.08x0.95mm_HandSolder
C56: 12; C_0603_1608Metric_Pad1.08x0.95mm_HandSolder
C59, C111: 4.7; C_0603_1608Metric_Pad1.08x0.95mm_HandSolder
C63, C78: 1u; C_0603_1608Metric_Pad1.08x0.95mm_HandSolder
C66, C67, C68, C74, C75, C86, C87: 5.6; L_0805_2012Metric
C70, C71, C76, C85: 100n; C_1210_3225Metric
C79, C104: 2.2u; C_0603_1608Metric_Pad1.08x0.95mm_HandSolder
C81, C84: 470; C_0603_1608Metric_Pad1.08x0.95mm_HandSolder
C83: 220uF; CP_Elec_6.3x5.8
C88: 1.6; C_0805_2012Metric
C89: 4.7; C_0805_2012Metric_Pad1.18x1.45mm_HandSolder
C95: 0.5+1.3; C_0805_2012Metric
C96, C99, C110, C112: 100n; C_0805_2012Metric_Pad1.18x1.45mm_HandSolder
C97, C109, C113: 22u; C_1206_3216Metric_Pad1.33x1.80mm_HandSolder
C98: 1.3; C_0805_2012Metric
C100, C108: 100n; C_1206_3216Metric
C102, C107: 100n; C_0603_1608Metric
D1: SMAJ30CA; D_SMA
D2: SMAJ15CA-TP; D_SMA
D3: BAT54; D_SOD-123
D4: BAR64; D_SOD-523
D5: INFO; LED_0805_2012Metric_Pad1.15x1.40mm_HandSolder
D6, D7: BAV99; SOT-23-3
D8: LOCK; LED_0805_2012Metric_Pad1.15x1.40mm_HandSolder
F1: 1.85A; Fuse_2920_7451Metric_Pad2.10x5.45mm_HandSolder
F2: 100mA; Fuse_1210_3225Metric_Pad1.42x2.65mm_HandSolder
F3: 500mA; Fuse_1206_3216Metric_Pad1.42x1.75mm_HandSolder
FL1: ECMS1V0905-222-R; L_CommonModeChoke_TDK_ACM7060
FL2, FL3: TA0532A; Filter_SAW_Epcos_DCC6C_3x3mm
IC1: RFFC2071TR13
IC2: MHT2012NT1
J1: VCC+PTT; 874370363
J2: TRX; SMA_Wurth_60312102114405_Vertical
J3: SWD ISP; PinHeader_2x03_P2.54mm_Vertical_SMD
J4: RX_OUT / 25M_REF; SMA_Wurth_60312102114405_Vertical
J5: LNB; SMA_Wurth_60312102114405_Vertical
J6: TX; SMA_Wurth_60312102114405_Vertical
JP1, JP2, JP4, JP6: SolderJumper_3_Open; SolderJumper-3_P1.3mm_Bridged12_RoundedPad1.0x1.5mm_NumberL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
JP5: SolderJumper_2_Open; SolderJumper-2_P1.3mm_Bridged_RoundedPad1.0x1.5mm
JP7: SolderJumper_2_Open; SolderJumper-2_P1.3mm_Open_RoundedPad1.0x1.5mm
L1, L15, L18, L20: FB; L_1812_4532Metric_Pad1.30x3.40mm_HandSolder
L2: 0.22u; L_0805_2012Metric_Pad1.05x1.20mm_HandSolder
L3: 1u; L_0805_2012Metric_Pad1.05x1.20mm_HandSolder
L4, L5: FB; L_0402_1005Metric
L6, L21: BK1608HM102TL; L_0603_1608Metric_Pad1.05x0.95mm_HandSolder
L7: 120n; L_0805_2012Metric_Pad1.05x1.20mm_HandSolder
L8: 10n; L_0603_1608Metric_Pad1.05x0.95mm_HandSolder
L9: 180nH; L_0805_2012Metric_Pad1.05x1.20mm_HandSolder
L10: 1u; L_0603_1608Metric_Pad1.05x0.95mm_HandSolder
L11: 220n; L_0603_1608Metric_Pad1.05x0.95mm_HandSolder
L12: FB; L_Walsin_WLFM201209x
L14: 3.3n; L_0805_2012Metric_Pad1.05x1.20mm_HandSolder
L16: FB; Fuse_1812_4532Metric_Pad1.30x3.40mm_HandSolder
L17, L19: 2.2u; INDPM7168X300N
PTT: PTT; TestPoint_Pad_D1.5mm
Q1: BC848; SOT-23
Q2: BC847C; SOT-23
Q3, Q6: BSS84P; SOT-23
Q4: MMBT3904; SOT-23
Q5: MJE122; PinHeader_1x03_P1.27mm_Vertical
R1, R3: 4k7; R_0603_1608Metric_Pad0.98x0.95mm_HandSolder
R2, R8, R33: 100k; R_0603_1608Metric_Pad0.98x0.95mm_HandSolder
R4, R5, R26, R51, R52, R53: 10k; R_0603_1608Metric_Pad0.98x0.95mm_HandSolder
R6, R50, R57: 47k; R_0603_1608Metric_Pad0.98x0.95mm_HandSolder
R7, R10, R36, R48: 1k; R_0603_1608Metric_Pad0.98x0.95mm_HandSolder
R9: 39k; R_0603_1608Metric_Pad0.98x0.95mm_HandSolder
R11: 22k; R_0603_1608Metric_Pad0.98x0.95mm_HandSolder
R12: 56/5W; R_Axial_DIN0614_L14.3mm_D5.7mm_P15.24mm_Horizontal
R13: 1k5; R_0603_1608Metric_Pad0.98x0.95mm_HandSolder
R14, R17: 470; R_0603_1608Metric_Pad0.98x0.95mm_HandSolder
R15, R18, R20: 0; R_0603_1608Metric_Pad0.98x0.95mm_HandSolder
R16, R21, R23: 220; R_0603_1608Metric_Pad0.98x0.95mm_HandSolder
R19: 56; R_0603_1608Metric_Pad0.98x0.95mm_HandSolder
R22: 51k 1%; R_0603_1608Metric_Pad0.98x0.95mm_HandSolder
R24: 6.8k; R_0603_1608Metric_Pad0.98x0.95mm_HandSolder
R25: 15k; R_0603_1608Metric_Pad0.98x0.95mm_HandSolder
R27: 2.7k; R_0603_1608Metric_Pad0.98x0.95mm_HandSolder
R28, R30, R32: 16; R_0603_1608Metric_Pad0.98x0.95mm_HandSolder
R29, R35, R41, R43, R46, R49: 270; R_0603_1608Metric_Pad0.98x0.95mm_HandSolder
R31, R42, R47: 18; R_0603_1608Metric_Pad0.98x0.95mm_HandSolder
R37: 330; R_0603_1608Metric_Pad0.98x0.95mm_HandSolder
R38: 3; R_1812_4532Metric
R39, R40: 2k2; R_0603_1608Metric_Pad0.98x0.95mm_HandSolder
R44, R45: 22k 1%; R_0805_2012Metric_Pad1.20x1.40mm_HandSolder
R54, R55: 4.7k; R_0603_1608Metric_Pad0.98x0.95mm_HandSolder
R56: 560k; R_0603_1608Metric_Pad0.98x0.95mm_HandSolder
RV1: 2k2; Potentiometer_Bourns_TC33X_Vertical
RV2: 2k2; Potentiometer_Bourns_3269W_Vertical
RV3, RV4: 5k; Potentiometer_Bourns_TC33X_Vertical
SW1: SW_DIP_x03; SW_DIP_SPSTx03_Slide_KingTek_DSHP03TJ_W5.25mm_P1.27mm_JPin
T1, T4: ETC1.6-4-2-3TR; ETC1.6-4-2-3TR_MCM
T2, T3: MABACT0039; MABACT0039_MCM
TH1: 10k; PinHeader_1x02_P1.27mm_Vertical
U1: STM32L011D4P6TR; TSSOP-14_4.4x5mm_P0.65mm
U2: LM321; SOT-23-5
U3: SKY66292-11; QFN16_5X5_SKY
U4: 74LVC2G17; Vishay_PowerPAK_SC70-6L_Dual
U5: TPS73633DBVRG4; SOT-23-5
U6: LP2985-18DBVR; SOT-23-5
U7: MIC5219-3.0YMM; MSOP-8_3x3mm_P0.65mm
U8, U9: TLV74130PDBVR; SOT-23-5
U10: MAX20457ATIF/VY+; 21-100130_MXM
U11: L78L09ACUTR; SOT-89-3
VBUS: 28V; TestPoint_Pad_D1.5mm
X1, X2: TA1862A; Filter_SAW_Epcos_DCC6C_3x3mm
Y1: LFTVXO076346 25MHz; LFTVXO076346REEL_IQD-M
rx: RX

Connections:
+1V8: C62.1, L21.1, R44.1, U4.5 (VCC)
+2V8: C11.2, J3.1, U1.10 (VDD), U9.5 (OUT)
+3.3V: C46.2, C94.2, L6.1, U5.5 (OUT), U6.1 (VIN), U6.3 (ON/~OFF)
+3V0/A: 3Va.1, C34.1, C79.2, L4.2, L5.2, U7.3 (OUT)
+3V0/D: 3Vd.1, C18.1, C21.1, C23.2, IC1.19 (DIG_VDD), IC1.29 (RESETX), L12.1
+5V: 5V.1, C49.1, C50.1, C53.1, C54.1, C57.1, C60.1, C61.1, C63.2, C90.2, C91.2, C92.2, C93.2, C96.2, L15.1, U3.5 (VBIAS), U3.12 (VCC3), U3.14 (VCC2), U3.16 (VCC1), U5.1 (IN), U5.3 (EN), U7.1 (EN), U7.2 (IN), U8.1 (IN), U8.3 (EN), U9.1 (IN), U9.3 (EN)
+9V: 9V.1, C41.1, C64.1, C103.2, Q6.2 (S), R24.2, R25.2, U2.5 (V+), U11.1 (OUT)
+13V: 13V.1, C6.1, C48.2, C105.2, C112.2, F3.1, JP5.2 (B), L20.2, Q3.2 (S), R3.1, R6.1, U11.3 (IN)
/ANA_VDD2: C28.2, C31.1, C33.1, C35.2, IC1.22 (ANA_VDD2), L5.1, T1.2, T4.2
/LNB_REF: JP6.2 (C), U4.4
/PLL_REF: C29.1, U4.6
/RFFC_ENX: C22.2, IC1.30 (ENX), R20.1
/RFFC_SCLK: C20.2, IC1.31 (SCLK), R18.1
/RFFC_SDATA: C17.2, IC1.32 (SDATA), R15.1
/SUPSW: C100.2, C101.2, L16.2, U10.2 (EN2), U10.3 (EN1), U10.6 (SUPSW1)
/SWCLK: J3.4, U1.14 (PA14)
/SWDIO: J3.2, U1.13 (PA13)
//PA_ENABLE: D3.2 (A), PTT.1, Q1.3 (C), R3.2, R4.1, R8.1, R48.2
GND: C3.1, C4.1, C5.2, C6.2, C7.2, C8.2, C9.1, C11.1, C14.1, C15.2, C17.1, C18.2, C19.2, C20.1, C21.2, C22.1, C23.1, C25.2, C27.2, C28.1, C30.2, C31.2, C32.2, C33.2, C34.2, C35.1, C37.2, C39.2, C41.2, C43.2, C44.2, C45.2, C46.1, C47.1, C48.1, C49.2, C50.2, C52.1, C53.2, C54.2, C55.1, C56.2, C57.2, C58.1, C60.2, C61.2, C62.2, C63.1, C64.2, C65.2, C66.2, C67.2, C68.2, C69.2, C70.2, C71.2, C72.2, C73.2, C74.1, C75.1, C76.2, C77.1, C78.1, C79.1, C80.1, C81.1, C82.2, C83.1, C84.1, C85.2, C86.1, C87.1, C88.1, C90.1, C91.1, C92.1, C93.1, C94.1, C95.1, C96.1, C97.1, C98.1, C99.1, C100.1, C101.1, C103.1, C104.1, C105.1, C106.1, C108.1, C109.1, C110.1, C112.1, C113.1, D5.1 (K), D6.3 (K), D7.3 (K), D8.1 (K), FL1.4, FL2.1 (GND), FL2.3 (GND), FL2.4 (GND), FL2.6 (GND), FL3.1 (GND), FL3.3 (GND), FL3.4 (GND), FL3.6 (GND), IC1.12 (TM), IC1.33 (GND), IC2.25 (EP), J2.2 (Ext), J3.5, J4.2 (Ext), J5.2 (Ext), J6.2 (Ext), L8.1, Q1.2 (E), Q2.2 (E), Q4.2 (E), R2.2, R5.2, R9.2, R12.1, R19.2, R22.1, R26.1, R29.1, R35.1, R38.2, R40.1, R41.1, R43.1, R45.2, R46.1, R49.1, R51.2, R52.1, R53.1, R57.2, SW1.1, SW1.2, SW1.3, TH1.2, U1.9 (VSS), U2.2 (V-), U3.1 (GND), U3.3 (GND), U3.4 (GND), U3.7 (GND), U3.8 (GND), U3.10 (GND), U3.11 (GND), U3.13 (GND), U3.15 (GND), U3.17 (EPAD), U4.2 (GND), U5.2 (GND), U6.2 (GND), U7.5 (GND), U7.6 (GND), U7.7 (GND), U7.8 (GND), U8.2 (GND), U9.2 (GND), U10.1 (PGND), U10.11 (PGND1), U10.12 (PGND2), U10.19 (PGND), U10.20 (PGND), U10.23 (PGND), U10.24 (PGND), U10.25 (AGND), U10.27 (EXTVCC), U10.29 (EPAD), U11.2 (GND), X1.1 (GND), X1.3 (GND), X1.4 (GND), X1.6 (GND), X2.1 (GND), X2.3 (GND), X2.4 (GND), X2.6 (GND), Y1.2 (GND)
unnamed: C1.3, FL1.1
unnamed: C2.1, L1.1
unnamed: C7.1, C8.1, L2.1, R10.2
unnamed: C12.2, R11.1
unnamed: C15.1, R14.1, R17.2
unnamed: C24.1, T2.3
unnamed: C25.1, T2.1
unnamed: C26.1, T1.5
unnamed: C27.1, T1.4
unnamed: C36.1, T3.4
unnamed: C37.1, T3.5
unnamed: C39.1, T4.4
unnamed: C40.1, T4.5
unnamed: C40.2, R29.2, R31.1
unnamed: C51.1, C59.2, L8.2
unnamed: C55.2, C58.2, F3.2, L10.1
unnamed: C56.1, L7.2, L9.1
unnamed: C88.2, C89.2
unnamed: C89.1, C95.2, L14.1
unnamed: C102.2, L17.2, U10.9 (LX1), U10.10 (LX1)
unnamed: C1.2, C2.2, D1.1 (A1), D2.2 (A2), FL1.2, J1.2
unnamed: C1.1, D1.2 (A2), F1.2
unnamed: C2.3, D2.1 (A1), F2.2
unnamed: C3.2, D3.1 (K), L1.2
unnamed: C16.1, D4.2 (A), L3.1, rx.1
unnamed: C10.2, D4.1 (K), R12.2, R13.1
unnamed: D5.2 (A), R16.1
unnamed: C24.2, D6.1 (K), D6.2 (A), R19.1, RV1.1, RV1.2
unnamed: C16.2, C26.2, D7.1 (K), D7.2 (A)
unnamed: D8.2 (A), R21.2
unnamed: FL2.2 (IN), R31.2, R35.2
unnamed: C45.1, FL2.5 (OUT), FL3.2 (IN)
unnamed: FL3.5 (OUT), R41.2, R42.1
unnamed: IC1.13 (MIX1_IPN), T3.1
unnamed: IC1.14 (MIX1_IPP), T3.3
unnamed: IC1.17 (MIX1_OPN), T1.3
unnamed: IC1.18 (MIX1_OPP), T1.1
unnamed: IC1.24 (MIX2_IPN), T2.5
unnamed: IC1.23 (MIX2_IPP), T2.4
unnamed: IC1.27 (MIX2_OPN), R23.1, T4.3
unnamed: IC1.28 (MIX2_OPP), R23.2, T4.1
unnamed: C30.1, C32.1, IC1.5 (ANA_VDD1), L4.1
unnamed: IC1.26 (GPO4/LD/DO), R21.1
unnamed: C12.1, C13.1, IC1.6 (LFILT1)
unnamed: C13.2, IC1.7 (LFILT2), R11.2, R14.2
unnamed: C19.1, IC1.8 (LFILT3), R17.1
unnamed: C29.2, IC1.10 (REF_IN)
unnamed: IC1.4 (REXT), R22.2
unnamed: IC2.3 (RFIN_1), IC2.4 (RFIN_2), R47.2, R49.2
unnamed: IC2.13 (N/C), IC2.14 (N/C), IC2.15 (VDS2_1)
unnamed: C66.1, C67.1, C71.1, C72.1, IC2.23 (N/C), IC2.24 (VGS1), R54.2
unnamed: C68.1, C69.1, C70.1, IC2.7 (N/C), IC2.8 (VGS2), R55.2
unnamed: F2.1, J1.1
unnamed: F1.1, J1.3
unnamed: C10.1, J2.1 (In), R1.1
unnamed: C14.2, J3.3, U1.4 (NRST)
unnamed: C38.2, J4.1 (In)
unnamed: C59.1, J5.1 (In), JP7.2 (B), L11.2
unnamed: C98.2, J6.1 (In), L14.2
unnamed: JP1.1 (A), JP6.3 (B)
unnamed: JP1.3 (B), R30.2
unnamed: C38.1, JP1.2 (C)
unnamed: JP2.1 (A), JP4.1 (A)
unnamed: JP2.3 (B), R28.1
unnamed: C36.2, JP2.2 (C)
unnamed: JP4.3 (B), R32.1
unnamed: JP4.2 (C), X1.2 (IN)
unnamed: C44.1, JP5.1 (A), Q5.2 (C)
unnamed: JP6.1 (A), L7.1
unnamed: JP7.1 (A), L9.2
unnamed: L2.2, L3.2
unnamed: L10.2, L11.1
unnamed: C5.1, Q1.1 (B), R1.2, R2.1
unnamed: Q2.1 (B), R4.2, R5.1
unnamed: Q2.3 (C), R6.2, R7.2
unnamed: Q3.3 (D), R10.1
unnamed: Q3.1 (G), R7.1
unnamed: Q4.1 (B), R37.2
unnamed: C42.1, Q4.3 (C), Q5.1 (B), R36.2
unnamed: C42.2, Q5.3 (E), R37.1, R38.1
unnamed: Q6.3 (D), R50.1, RV3.1, RV4.3
unnamed: Q6.1 (G), R48.1
unnamed: R13.2, RV1.3
unnamed: R25.1, R26.2, R27.1
unnamed: R28.2, R30.1, R32.2
unnamed: R33.2, R36.1, U2.4
unnamed: R39.1, RV2.3
unnamed: R40.2, RV2.1
unnamed: R52.2, RV3.3
unnamed: R53.2, RV4.1
unnamed: R54.1, RV4.2
unnamed: R55.1, RV3.2
unnamed: SW1.4, U1.5 (PA0)
unnamed: SW1.5, U1.6 (PA1)
unnamed: SW1.6, U1.7 (PA4)
unnamed: R15.2, U1.8 (PA7)
unnamed: R18.2, U1.11 (PA9)
unnamed: R20.2, U1.12 (PA10)
unnamed: C9.2, R8.2, R9.1, U1.2 (PC14)
unnamed: R16.2, U1.3 (PC15)
unnamed: R24.1, TH1.1, U2.1 (+)
unnamed: R27.2, R33.1, U2.3 (-)
unnamed: C65.1, R50.2, R51.1, U3.6 (PAEN)
unnamed: R42.2, R43.2, U3.2 (RFIN)
unnamed: R46.2, R47.1, U3.9 (RFOUT)
unnamed: C80.2, U5.4 (NR)
unnamed: C81.2, U6.4 (BP)
unnamed: C77.2, L21.2, U6.5 (VOUT)
unnamed: C84.2, U7.4 (BP)
unnamed: C78.2, L12.2, U8.5 (OUT)
unnamed: C104.2, U10.5 (FB1), U10.26 (BIAS)
unnamed: C102.1, U10.7 (BST1)
unnamed: C107.1, U10.15 (BST2)
unnamed: C111.1, R56.2, R57.1, U10.17 (FB2)
unnamed: C107.2, L19.1, U10.13 (LX2)
unnamed: C97.2, C113.2, L15.2, L17.1, U10.4 (OUT1)
unnamed: C109.2, C111.2, L19.2, L20.1, R56.1, U10.18 (OUT2)
unnamed: C106.2, C108.2, L18.1, U10.16 (SUPSW2)
unnamed: C43.1, X1.5 (OUT), X2.2 (IN)
unnamed: C51.2, X2.5 (OUT)
unnamed: R44.2, R45.1, U4.1, U4.3, Y1.4 (OUT)
unnamed: C47.2, RV2.2, Y1.1 (VC)
unnamed: C52.2, L6.2, R39.2, Y1.5 (VS)
VBUS: C4.2, C73.1, C74.2, C75.2, C76.1, C82.1, C83.2, C85.1, C86.2, C87.2, C99.2, C110.2, FL1.3, IC2.9 (N/C), IC2.10 (VDS1), IC2.11 (N/C), IC2.16 (VDS2_2), IC2.17 (N/C), IC2.18 (N/C), L16.1, L18.2, VBUS.1

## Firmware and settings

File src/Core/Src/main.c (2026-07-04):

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
/* Includes ------------------------------------------------------------------*/
#include "main.h"

/* USER CODE BEGIN Includes */
#include "mixer.h"
#include "rffc5071.h"
#include "rffc5071_spi.h"
#include <stdbool.h>

/* USER CODE END Includes */


void SystemClock_Config(void);
static void MX_GPIO_Init(void);

/* USER CODE BEGIN 0 */

BAND_IF getBand() {
	// read band IF setting
	GPIO_PinState bandswitch[3];
	bandswitch[0] = HAL_GPIO_ReadPin(BANDSWITCH_1_GPIO_Port, BANDSWITCH_1_Pin);
	bandswitch[1] = HAL_GPIO_ReadPin(BANDSWITCH_1_GPIO_Port, BANDSWITCH_2_Pin);
	bandswitch[2] = HAL_GPIO_ReadPin(BANDSWITCH_1_GPIO_Port, BANDSWITCH_3_Pin);
	BAND_IF band = !bandswitch[0] + (!bandswitch[1] << 1) + (!bandswitch[2] << 2);
	return band;
}

void switchBand(rffc5071_driver_t *const mixer, BAND_IF band) {
	rffc5071_setup(mixer, band);
	rffc5071_rx(mixer);

	HAL_GPIO_WritePin(LED_GPIO_Port, LED_Pin, GPIO_PIN_RESET);
	for(int x=0; x<=band; x++) {
	  HAL_GPIO_WritePin(LED_GPIO_Port, LED_Pin, GPIO_PIN_RESET);
	  HAL_Delay(400);
	  HAL_GPIO_WritePin(LED_GPIO_Port, LED_Pin, GPIO_PIN_SET);
	  HAL_Delay(200);
	}
}

/* USER CODE END 0 */

/**
  * @brief  The application entry point.
  * @retval int
  */
int main(void)
{

  /* MCU Configuration--------------------------------------------------------*/

  /* Reset of all peripherals, Initializes the Flash interface and the Systick. */
  HAL_Init();

  /* Configure the system clock */
  SystemClock_Config();

  /* Initialize all configured peripherals */
  MX_GPIO_Init();
  /* USER CODE BEGIN 2 */

  // read band IF setting
  BAND_IF band = getBand();

  // initialize PLL and mixer, don't enable them yet
  rffc5071_driver_t* mix = mixer_bus_setup();
  rffc5071_setup(mix, band);

  // indicate band
  //TODO debug only
  HAL_GPIO_WritePin(LED_GPIO_Port, LED_Pin, GPIO_PIN_RESET);
  for(int x=0; x<=band; x++) {
	  HAL_GPIO_WritePin(LED_GPIO_Port, LED_Pin, GPIO_PIN_RESET);
	  HAL_Delay(400);
	  HAL_GPIO_WritePin(LED_GPIO_Port, LED_Pin, GPIO_PIN_SET);
	  HAL_Delay(200);
  }

  /* USER CODE END 2 */

  /* Infinite loop */
  /* USER CODE BEGIN WHILE */

  	// PTT polling loop: switch PLL bank & mixer
	GPIO_PinState ptt = PTT_RX;
	GPIO_PinState prev_ptt = PTT_TX;
	band = getBand();
	BAND_IF prev_band = getBand();
	const uint8_t pollingStepMs = 10;
	uint16_t loopCounter = 0;
	bool txing;
	while (1) {
		// handle ptt switch
		if (ptt != prev_ptt) {
			if (ptt == PTT_TX) {
				txing = true;
				rffc5071_tx(mix);
				HAL_GPIO_WritePin(LED_GPIO_Port, LED_Pin, GPIO_PIN_SET);
			} else { // RX
				txing = false;
				rffc5071_rx(mix);
				HAL_GPIO_WritePin(LED_GPIO_Port, LED_Pin, GPIO_PIN_RESET);
			}
		}
		prev_ptt = ptt;
		ptt = HAL_GPIO_ReadPin(PTT_GPIO_Port, PTT_Pin);

		// handle band switch
		if (band != prev_band) {
			switchBand(mix, band);
		}
		prev_band = band;
		band = getBand();

		HAL_Delay(pollingStepMs);

		// short blinks every 1s (TODO calc from step time)
		if (loopCounter % 100 == 0) {
			HAL_GPIO_WritePin(LED_GPIO_Port, LED_Pin, GPIO_PIN_SET);
		} else if (loopCounter % 25 == 1 && !txing) {
			HAL_GPIO_WritePin(LED_GPIO_Port, LED_Pin, GPIO_PIN_RESET);
		}
		loopCounter++;
	}


    /* USER CODE END WHILE */

}

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


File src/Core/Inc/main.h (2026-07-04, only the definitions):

#define BANDSWITCH_1_Pin GPIO_PIN_4
#define BANDSWITCH_1_GPIO_Port GPIOA
#define BANDSWITCH_2_Pin GPIO_PIN_1
#define BANDSWITCH_2_GPIO_Port GPIOA
#define BANDSWITCH_3_Pin GPIO_PIN_0
#define BANDSWITCH_3_GPIO_Port GPIOA
#define RFFC_Port GPIOA
#define RFFC_ENX_Pin GPIO_PIN_10
#define RFFC_SCLK_Pin GPIO_PIN_9
#define RFFC_SDATA_Pin GPIO_PIN_7
#define LED_GPIO_Port GPIOC
#define LED_Pin GPIO_PIN_15
#define PTT_GPIO_Port GPIOC
#define PTT_Pin GPIO_PIN_14
#define PTT_RX GPIO_PIN_SET
#define PTT_TX GPIO_PIN_RESET

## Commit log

2026-06-30 code upload
    [ptt_companion.kicad_pcb, ptt_companion.kicad_sch, trv.kicad_pcb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]
2026-06-30 add circuit description section to README

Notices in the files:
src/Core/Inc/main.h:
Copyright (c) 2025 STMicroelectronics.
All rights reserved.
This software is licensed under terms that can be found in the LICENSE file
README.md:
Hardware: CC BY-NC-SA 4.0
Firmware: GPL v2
